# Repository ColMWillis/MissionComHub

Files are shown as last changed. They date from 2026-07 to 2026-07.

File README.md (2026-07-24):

# Mission Communications Hub Mk I

**Branding:** Mission Communications Hub / Mk I / GAWG CAP

**Current mechanical revision:** R0.12 side-by-side PD carrier and matching lid

MissionComHub is an experimental portable power-interface enclosure for a Peplink MAX BR1 Pro 5G and Starlink Mini using an Anker SOLIX C200 DC or equivalent USB-C PD source. It is designed for temporary CAP aircraft, ground-vehicle, and mission-base use.

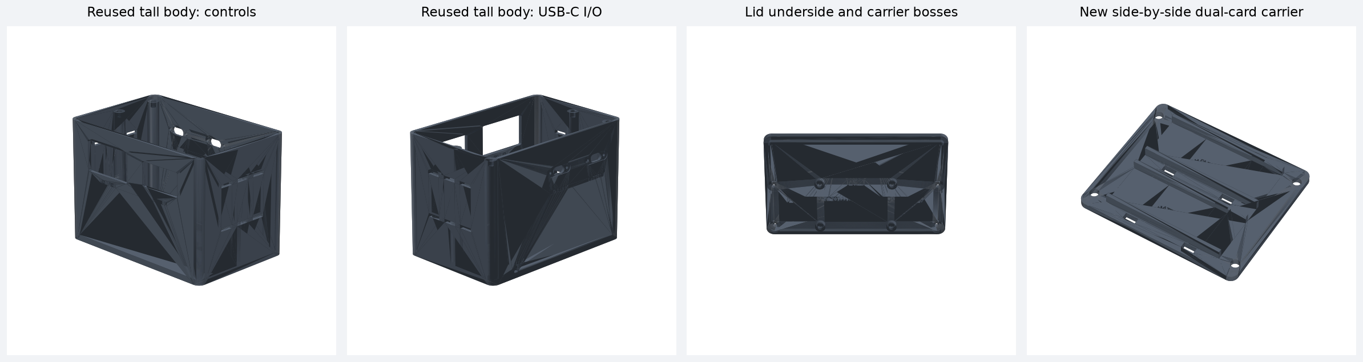
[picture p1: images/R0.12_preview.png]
Mission Communications Hub R0.12 preview


## R0.12 configuration

- 146 × 96 × 103 mm PETG-CF body
- Separate 4 mm serviceable lid with locating lip and raised branding
- Power switch opening: 38.55 × 20.77 mm
- Fit-tested voltmeter opening: 45.17 × 26.39 mm
- Two refactored USB-C panel positions for the received cable-backed fittings
- Confirmed 18.55 mm USB-C mounting centers
- 13.20 × 6.85 mm printed pass-throughs for the measured 12.70 × 6.35 mm bodies
- 25.80 × 8.02 mm rounded flange pockets for the measured 25.40 × 7.62 mm flanges
- Fit-tested 4.10 × 2.40 mm bonded-cable exit for the Peplink lead
- Enlarged 4.55 × 2.70 mm strain-relief channel and two-screw clamp
- Internal Blue Sea Systems 5045 mounting bosses at 65.1 mm centers
- Internal unfused-busbar bosses at the confirmed 120.65 mm (4.75 inch) centers
- A clear central cable channel with four tie-down points
- Correctly oriented exterior `BATTERY`, `STARLINK`, and `PEPLINK` I/O labels
- Exterior `VOLTAGE` and `POWER` control labels
- Blue Sea 5045 fused-block riser coupon
- Full-envelope unfused-busbar riser coupon with fixed 120.65 mm centers
- Final engraved USB-C coupon at 18.55 mm centers
- Revised lid with a compact four-boss carrier pattern
- Removable 64 × 54 mm side-by-side carrier for two USB-PD cards
- Rails moved inward 1 mm per side and raised 2 mm
- Open USB ends plus 20 mm power-wire service zones at the screw terminals
- Open-ended card guides and two zip ties per card
- Documented battery-input and Starlink-output card placement under the lid
- Blue Sea 5045 moved to the I/O half
- Unfused bus bar moved to the control half
- Switch, voltmeter, and USB-C interfaces raised to a 77 mm centerline
- Explicit clearance validation for the switch’s measured 38.10 mm inward depth

R0.12 reuses the validated R0.11 tall body. It replaces the tandem carrier and lid after physical fitting showed an attached USB plug extending beyond the enclosure and the received boards falling between the original rails.

## Download and print

- Complete package: [`releases/R0.12/MissionComHub_MkI_Enclosure_R0.12.zip`](releases/R0.12/MissionComHub_MkI_Enclosure_R0.12.zip)
- 3MF files: [`CAD/3MF/R0.12`](CAD/3MF/R0.12)
- STL files: [`CAD/STL/R0.12`](CAD/STL/R0.12)
- STEP files: [`CAD/STEP/R0.12`](CAD/STEP/R0.12)
- Parametric CadQuery generator: [`CAD/CadQuery/make_mch_mk1_r12.py`](CAD/CadQuery/make_mch_mk1_r12.py)
- Dimensions, placement map, and validation: [`CAD/Releases/R0.12`](CAD/Releases/R0.12)

Reuse the R0.11 body. Print the R0.12 lid and carrier; the tandem R0.10/R0.11 carrier is obsolete.

## Suggested prototype settings

- Prusa CORE One
- PETG-CF with a hardened 0.4 mm nozzle
- 0.20 mm layer height
- 4 perimeters
- 5 top and bottom layers
- 25–35% gyroid infill

The branded lid needs slicer support beneath its center when printed branding-up. See the release README for orientation guidance.

## Validation status

Every R0.12 STL and 3MF is watertight with consistent winding. STEP files re-import as valid solids. Body/lid, carrier, card, attached USB plug, power-wire service zone, switch, and both power-block checks report zero interference.

## Repository layout

- `CAD/CadQuery/` — parametric source
- `CAD/3MF/`, `CAD/STL/`, `CAD/STEP/` — synchronized manufacturing exports
- `CAD/Releases/` — dimensions, checksums, and validation reports
- `docs/` — requirements, design specification, BOM, assembly, and tests
- `images/` — previews and future build photographs
- `releases/` — complete downloadable release archives
- `tools/` — validation and preview utilities

## Safety

This is experimental mission-support equipment, not certified avionics. It must not interfere with aircraft controls, emergency egress, required equipment, weight and balance, or approved aircraft systems. Electrical architecture, wire sizing, fuse selection, thermal performance, and flight restraint must be independently verified before operational use.

## License

Documentation and mechanical designs are released under CERN-OHL-P-2.0 unless a file states otherwise. Software uses the MIT License where applicable.

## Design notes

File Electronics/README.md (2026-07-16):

# Electronics

Reserved for Milestone 2 electrical design:

- power architecture
- wiring harness drawings
- connector pinouts
- fuse schedule
- load budget
- test records

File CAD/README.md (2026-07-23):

# CAD Files

The current parametric source of truth is [`CadQuery/make_mch_mk1_r09.py`](CadQuery/make_mch_mk1_r09.py).

R0.9 final-draft exports are organized by format:

- [`3MF/R0.9`](3MF/R0.9) — print meshes in millimeter units
- [`STL/R0.9`](STL/R0.9) — triangulated print meshes
- [`STEP/R0.9`](STEP/R0.9) — neutral editable solids for Fusion and other CAD tools
- [`Releases/R0.9`](Releases/R0.9) — README, dimensions, checksums, and validation results

All three export formats were generated from the same CadQuery source. The complete packaged release is under [`../releases/R0.9`](../releases/R0.9).

## R0.9 printable objects

1. Main enclosure body
2. Branded locating-lip lid
3. Peplink bonded-cable strain-relief clamp
4. Control fit coupon
5. Final 18.55 mm USB-C fit coupon
6. Peplink wire-exit fit coupon
7. Blue Sea 5045 fused-block riser coupon
8. Unfused-busbar riser coupon at confirmed 120.65 mm centers

## R0.8A USB-C refinement coupon

`MCH-MkI_USB-C_panel_fit_coupon_18.70-18.75_R0.8A` is a focused two-position coupon created after the 18.80 mm position was slightly loose. The left opening is 18.75 mm and the right opening is 18.70 mm. The enclosure body is not changed until this coupon identifies the preferred fit.

## R0.8B fit refinement coupons

- `MCH-MkI_USB-C_panel_fit_coupon_18.60-18.65_R0.8B`: left position 18.65 mm; right position 18.60 mm.
- `MCH-MkI_unfused_busbar_riser_coupon_120.65mm_R0.8B`: fixed 120.65 mm (4.75 inch) mounting centers, 0.25 inch farther apart than the prior coupon.

Both measurements are engraved on their coupons. The enclosure body remains at the R0.8 dimensions until physical coupon testing identifies the final values.

## R0.8C USB-C refinement coupon

`MCH-MkI_USB-C_panel_fit_coupon_18.55mm_R0.8C` is a compact single-position coupon at 18.55 mm screw centers. This fit and the 120.65 mm busbar value were subsequently confirmed and incorporated into the R0.9 final draft.

Do not alter a mesh export without updating the parametric source and regenerating every synchronized format.

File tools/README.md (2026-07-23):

# Release Tools

The R0.5 validation and preview scripts require Python plus `cadquery`, `trimesh`, `numpy`, and `matplotlib`.

From the repository root:

```text
python tools/validate_release_r05.py
python tools/render_preview_r05.py
```

The validator reads the canonical files under `CAD/3MF/R0.5`, `CAD/STL/R0.5`, and `CAD/STEP/R0.5`. It updates the validation reports and repository checksums under `CAD/Releases/R0.5`.

For the current R0.6 release, use:

```text
python tools/validate_release_r06.py
python tools/render_preview_r06.py
```

For the current R0.7 release, use:

```text
python tools/validate_release_r07.py
python tools/render_preview_r07.py
```

For the current R0.8 release, use:

```text
python tools/validate_release_r08.py
python tools/render_preview_r08.py
```

For the R0.9 final draft, use:

```text
python tools/validate_release_r09.py
python tools/render_preview_r09.py
```

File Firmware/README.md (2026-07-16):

# Firmware

Reserved for future monitoring, display, telemetry, and network-management software. No firmware is required for the Milestone 1 enclosure.

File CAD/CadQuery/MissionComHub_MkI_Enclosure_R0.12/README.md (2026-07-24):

# Mission Communications Hub Mk I Enclosure R0.12 — Side-by-Side PD Carrier

Compact refactor based on measured components.

## Overall size
- Body: 146 x 96 x 103 mm
- Wall: 3.0 mm
- Separate 4.0 mm lid with locating lip and raised branding

## Control face
- Voltmeter opening: 45.17 x 26.39 mm
- Power switch opening: 38.55 x 20.77 mm

R0.12 reuses the validated R0.11 tall body and replaces the tandem PD carrier and its lid mounting pattern.

## R0.12 collision correction
- Body height: 103.0 mm, increased by 51.0 mm (2.01 inches)
- Measured switch inward depth: 38.10 mm
- Control and USB panel center height: 77.0 mm
- Unfused bus bar: control half, Y=-24.95 mm
- Blue Sea 5045 fused block: I/O half, Y=+22.10 mm
- Tall lid posts moved to the I/O half and kept outside the fused-block footprint

## I/O face
- Two measured panel mounts: 25.4 x 7.62 mm rounded flange, 18.55 mm confirmed screw centers
- Received pass-through body: 12.70 x 6.35 mm
- Printed connector opening: 13.20 x 6.85 mm; M2.5 clearance holes: 2.8 mm
- Flush flange pocket: 25.8 x 8.0 x 0.8 mm deep
- Peplink bonded-cable exit: 4.10 x 2.40 mm rounded slot
- Reduced two-screw strain-relief for the measured 3.81 x 2.03 mm bonded 20 AWG cable
- Strain-relief cable channel: 4.55 x 2.70 mm
- Correctly oriented engraved BATTERY, STARLINK, and PEPLINK labels
- Engraved VOLTAGE and POWER control-face labels

## Blue Sea 5045 mounting
- Documented body footprint reserved: 92.5 x 43.8 mm
- Two internal mounting bosses at 65.1 mm centers
- 3.6 mm pilot holes; verify the chosen M4 fastening method before final assembly
- Full riser coupon included
- Mounted in the I/O half after the R0.11 block swap

## Unfused bus bar
- Supplied cover envelope: 137.16 x 38.10 x 22.86 mm
- Supplied lower-base length: 119.38 mm
- Confirmed mounting centers: 120.65 mm (4.75 inches)
- Body and coupon use fixed 5.5 mm mounting holes
- Body enlarged to 146 x 96 mm so the covered block and fused block can mount side-by-side
- Mounted in the control half after the R0.11 block swap

## Cable accommodation
The obsolete PCB-backed USB shelves were removed because the received USB interfaces are cable-backed panel fittings. Routing rails and tie-down tabs retain service loops away from both power blocks.

## USB-PD card carrier
- Separate removable carrier: 64.0 x 54.0 x 2.4 mm
- Installs under the lid, centered at X=0, Y=17.0 mm over the fused-block half
- Two open-ended bays for 45.72 x 17.78 mm card envelopes
- Two parallel side-by-side bays; both USB-C sockets point toward +X
- Battery-input PD card occupies the lower-Y bay; Starlink-output PD card occupies the upper-Y bay
- Guide rails move inward 1.0 mm per side and rise to 3.6 mm
- USB ends remain open for attached plugs; screw-terminal ends remain open with 20 mm validated wire-service envelopes
- Two zip ties per card; no undocumented PCB mounting holes are assumed
- Four M3 screws secure the carrier to blind heat-set-insert bosses under the lid
- The flat carrier face mounts against the lid bosses; the guide rails and cards face into the enclosure
- A conservative 8.0 mm card-assembly depth clears the bus-bar cover in the validated assembly

See `PD_CARD_PLACEMENT.md` for the top-view map, assembly order, and wiring paths.

## Print order
1. Stop using the R0.9/R0.10 body for this hardware layout.
2. Reuse the validated R0.11 body; print the R0.12 lid and R0.12 carrier.
3. Do not reuse the tandem R0.10/R0.11 carrier.
4. Install four M3 heat-set inserts in the blind underside bosses.
5. Fit the two cards to the carrier with two small zip ties per card.
6. Attach the populated carrier to the lid with four M3 screws.
7. Reuse the R0.10 strain-relief clamp if already printed; its geometry is unchanged.

## Suggested print settings
- PETG-CF
- 0.4 mm hardened nozzle
- 0.20 mm layer height
- 4 perimeters
- 5 top/bottom layers
- 25-35% gyroid infill
- Body upright; lid branding upward
- Carrier rail-side upward; no support is expected
- Body: supports only where the slicer identifies control/I-O openings as necessary
- Lid: branding upward preserves the visible text; enable snug/organic supports beneath the broad center panel, or test a long-edge orientation with a brim

## Serviceability
- The 4 mm removable lid, corrected locating lip, and raised branding are preserved, with its body-screw holes relocated to the I/O half.
- The entire PD assembly comes away with the lid after four enclosure screws are removed.
- Leave service loops in both USB panel cables and the DC wiring before lifting the lid.
- Mk II shall add a captive hinge/tether so the wire harness never acts as the lid restraint.
- All external component geometry has a fit coupon. Print coupons before the body.
- The final USB coupon and both body interfaces use the confirmed 18.55 mm screw centers.
- The Blue Sea 5045 footprint is based on the manufacturer's documented 92.5 x 43.8 mm envelope and 65.1 mm mounting centers.

## Regenerating the files
Python 3.11 or newer is recommended. Install `cadquery` and `trimesh`, then run:

```text
python make_mch_mk1_r12.py
```

The generator writes synchronized STEP, STL, and millimeter-unit 3MF files into a `MissionComHub_MkI_Enclosure_R0.12` folder beside the script.

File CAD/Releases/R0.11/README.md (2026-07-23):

# Mission Communications Hub Mk I Enclosure R0.11 — Tall Swapped-Block Body

Compact refactor based on measured components.

## Overall size
- Body: 146 x 96 x 103 mm
- Wall: 3.0 mm
- Separate 4.0 mm lid with locating lip and raised branding

## Control face
- Voltmeter opening: 45.17 x 26.39 mm
- Power switch opening: 38.55 x 20.77 mm

R0.11 replaces the R0.10 body after the physical 38.10 mm switch depth conflicted with the fused block. The body is approximately 2 inches taller, the fused and unfused blocks exchange sides, and all panel controls are raised into a dedicated upper zone.

## R0.11 collision correction
- Body height: 103.0 mm, increased by 51.0 mm (2.01 inches)
- Measured switch inward depth: 38.10 mm
- Control and USB panel center height: 77.0 mm
- Unfused bus bar: control half, Y=-24.95 mm
- Blue Sea 5045 fused block: I/O half, Y=+22.10 mm
- Tall lid posts moved to the I/O half and kept outside the fused-block footprint

## I/O face
- Two measured panel mounts: 25.4 x 7.62 mm rounded flange, 18.55 mm confirmed screw centers
- Received pass-through body: 12.70 x 6.35 mm
- Printed connector opening: 13.20 x 6.85 mm; M2.5 clearance holes: 2.8 mm
- Flush flange pocket: 25.8 x 8.0 x 0.8 mm deep
- Peplink bonded-cable exit: 4.10 x 2.40 mm rounded slot
- Reduced two-screw strain-relief for the measured 3.81 x 2.03 mm bonded 20 AWG cable
- Strain-relief cable channel: 4.55 x 2.70 mm
- Correctly oriented engraved BATTERY, STARLINK, and PEPLINK labels
- Engraved VOLTAGE and POWER control-face labels

## Blue Sea 5045 mounting
- Documented body footprint reserved: 92.5 x 43.8 mm
- Two internal mounting bosses at 65.1 mm centers
- 3.6 mm pilot holes; verify the chosen M4 fastening method before final assembly
- Full riser coupon included
- Mounted in the I/O half after the R0.11 block swap

## Unfused bus bar
- Supplied cover envelope: 137.16 x 38.10 x 22.86 mm
- Supplied lower-base length: 119.38 mm
- Confirmed mounting centers: 120.65 mm (4.75 inches)
- Body and coupon use fixed 5.5 mm mounting holes
- Body enlarged to 146 x 96 mm so the covered block and fused block can mount side-by-side
- Mounted in the control half after the R0.11 block swap

## Cable accommodation
The obsolete PCB-backed USB shelves were removed because the received USB interfaces are cable-backed panel fittings. Routing rails and tie-down tabs retain service loops away from both power blocks.

## USB-PD card carrier
- Separate removable carrier: 114.0 x 30.0 x 2.4 mm
- Installs under the lid, centered at X=0, Y=25.0 mm over the fused-block half
- Two open-ended bays for 45.72 x 17.78 mm card envelopes
- Left bay: battery-input PD sink/trigger card
- Right bay: Starlink-output PD source card
- Two zip ties per card; no undocumented PCB mounting holes are assumed
- Four M3 screws secure the carrier to blind heat-set-insert bosses under the lid
- The flat carrier face mounts against the lid bosses; the guide rails and cards face into the enclosure
- A conservative 8.0 mm card-assembly depth clears the bus-bar cover in the validated assembly

See `PD_CARD_PLACEMENT.md` for the top-view map, assembly order, and wiring paths.

## Print order
1. Stop using the R0.9/R0.10 body for this hardware layout.
2. Print the complete R0.11 body and R0.11 lid.
3. Reuse an R0.10 carrier if already printed; its geometry is unchanged.
4. Install four M3 heat-set inserts in the blind underside bosses.
5. Fit the two cards to the carrier with two small zip ties per card.
6. Attach the populated carrier to the lid with four M3 screws.
7. Reuse the R0.10 strain-relief clamp if already printed; its geometry is unchanged.

## Suggested print settings
- PETG-CF
- 0.4 mm hardened nozzle
- 0.20 mm layer height
- 4 perimeters
- 5 top/bottom layers
- 25-35% gyroid infill
- Body upright; lid branding upward
- Carrier rail-side upward; no support is expected
- Body: supports only where the slicer identifies control/I-O openings as necessary
- Lid: branding upward preserves the visible text; enable snug/organic supports beneath the broad center panel, or test a long-edge orientation with a brim

## Serviceability
- The 4 mm removable lid, corrected locating lip, and raised branding are preserved, with its body-screw holes relocated to the I/O half.
- The entire PD assembly comes away with the lid after four enclosure screws are removed.
- Leave service loops in both USB panel cables and the DC wiring before lifting the lid.
- All external component geometry has a fit coupon. Print coupons before the body.
- The final USB coupon and both body interfaces use the confirmed 18.55 mm screw centers.
- The Blue Sea 5045 footprint is based on the manufacturer's documented 92.5 x 43.8 mm envelope and 65.1 mm mounting centers.

## Regenerating the files
Python 3.11 or newer is recommended. Install `cadquery` and `trimesh`, then run:

```text
python make_mch_mk1_r11.py
```

The generator writes synchronized STEP, STL, and millimeter-unit 3MF files into a `MissionComHub_MkI_Enclosure_R0.11` folder beside the script.

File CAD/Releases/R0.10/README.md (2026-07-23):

# Mission Communications Hub Mk I Enclosure R0.10 — USB-PD Carrier

Compact refactor based on measured components.

## Overall size
- Body: 146 x 96 x 52 mm
- Wall: 3.0 mm
- Separate 4.0 mm lid with locating lip and raised branding

## Control face
- Voltmeter opening: 45.17 x 26.39 mm
- Power switch opening: 38.55 x 20.77 mm

R0.10 preserves the physically confirmed R0.9 enclosure body and adds a removable dual USB-PD card carrier to a revised lid. The already-printing R0.9 body remains fully compatible.

## I/O face
- Two measured panel mounts: 25.4 x 7.62 mm rounded flange, 18.55 mm confirmed screw centers
- Received pass-through body: 12.70 x 6.35 mm
- Printed connector opening: 13.20 x 6.85 mm; M2.5 clearance holes: 2.8 mm
- Flush flange pocket: 25.8 x 8.0 x 0.8 mm deep
- Peplink bonded-cable exit: 4.10 x 2.40 mm rounded slot
- Reduced two-screw strain-relief for the measured 3.81 x 2.03 mm bonded 20 AWG cable
- Strain-relief cable channel: 4.55 x 2.70 mm
- Correctly oriented engraved BATTERY, STARLINK, and PEPLINK labels
- Engraved VOLTAGE and POWER control-face labels

## Blue Sea 5045 mounting
- Documented body footprint reserved: 92.5 x 43.8 mm
- Two internal mounting bosses at 65.1 mm centers
- 3.6 mm pilot holes; verify the chosen M4 fastening method before final assembly
- Full riser coupon included

## Unfused bus bar
- Supplied cover envelope: 137.16 x 38.10 x 22.86 mm
- Supplied lower-base length: 119.38 mm
- Confirmed mounting centers: 120.65 mm (4.75 inches)
- Body and coupon use fixed 5.5 mm mounting holes
- Body enlarged to 146 x 96 mm so the covered block and fused block can mount side-by-side

## Cable accommodation
The obsolete PCB-backed USB shelves were removed because the received USB interfaces are cable-backed panel fittings. Routing rails and tie-down tabs retain service loops away from both power blocks.

## USB-PD card carrier
- Separate removable carrier: 114.0 x 30.0 x 2.4 mm
- Installs under the lid, centered at X=0, Y=25.0 mm over the unfused bus bar
- Two open-ended bays for 45.72 x 17.78 mm card envelopes
- Left bay: battery-input PD sink/trigger card
- Right bay: Starlink-output PD source card
- Two zip ties per card; no undocumented PCB mounting holes are assumed
- Four M3 screws secure the carrier to blind heat-set-insert bosses under the lid
- The flat carrier face mounts against the lid bosses; the guide rails and cards face into the enclosure
- A conservative 8.0 mm card-assembly depth clears the bus-bar cover in the validated assembly

See `PD_CARD_PLACEMENT.md` for the top-view map, assembly order, and wiring paths.

## Print order
1. Keep or finish the R0.9 body; no body reprint is required.
2. Print the R0.10 lid and dual USB-PD card carrier.
3. Install four M3 heat-set inserts in the blind underside bosses.
4. Fit the two cards to the carrier with two small zip ties per card.
5. Attach the populated carrier to the lid with four M3 screws.
6. Print the strain-relief clamp only if an R0.9 clamp is not already available.

## Suggested print settings
- PETG-CF
- 0.4 mm hardened nozzle
- 0.20 mm layer height
- 4 perimeters
- 5 top/bottom layers
- 25-35% gyroid infill
- Body upright; lid branding upward
- Carrier rail-side upward; no support is expected
- Body: supports only where the slicer identifies control/I-O openings as necessary
- Lid: branding upward preserves the visible text; enable snug/organic supports beneath the broad center panel, or test a long-edge orientation with a brim

## Serviceability
- The R0.6 4 mm removable lid, corrected locating lip, M3 corner-boss pattern, and raised branding are preserved.
- The entire PD assembly comes away with the lid after four enclosure screws are removed.
- Leave service loops in both USB panel cables and the DC wiring before lifting the lid.
- All external component geometry has a fit coupon. Print coupons before the body.
- The final USB coupon and both body interfaces use the confirmed 18.55 mm screw centers.
- The Blue Sea 5045 footprint is based on the manufacturer's documented 92.5 x 43.8 mm envelope and 65.1 mm mounting centers.

## Regenerating the files
Python 3.11 or newer is recommended. Install `cadquery` and `trimesh`, then run:

```text
python make_mch_mk1_r10.py
```

The generator writes synchronized STEP, STL, and millimeter-unit 3MF files into a `MissionComHub_MkI_Enclosure_R0.10` folder beside the script.

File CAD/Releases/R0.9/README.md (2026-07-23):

# Mission Communications Hub Mk I Enclosure R0.9 Final Draft

Compact refactor based on measured components.

## Overall size
- Body: 146 x 96 x 52 mm
- Wall: 3.0 mm
- Separate 4.0 mm lid with locating lip and raised branding

## Control face
- Voltmeter opening: 45.17 x 26.39 mm
- Power switch opening: 38.55 x 20.77 mm

R0.9 incorporates all physically confirmed interface dimensions into the complete enclosure body. It is the final draft before full assembly testing.

## I/O face
- Two measured panel mounts: 25.4 x 7.62 mm rounded flange, 18.55 mm confirmed screw centers
- Received pass-through body: 12.70 x 6.35 mm
- Printed connector opening: 13.20 x 6.85 mm; M2.5 clearance holes: 2.8 mm
- Flush flange pocket: 25.8 x 8.0 x 0.8 mm deep
- Peplink bonded-cable exit: 4.10 x 2.40 mm rounded slot
- Reduced two-screw strain-relief for the measured 3.81 x 2.03 mm bonded 20 AWG cable
- Strain-relief cable channel: 4.55 x 2.70 mm
- Correctly oriented engraved BATTERY, STARLINK, and PEPLINK labels
- Engraved VOLTAGE and POWER control-face labels

## Blue Sea 5045 mounting
- Documented body footprint reserved: 92.5 x 43.8 mm
- Two internal mounting bosses at 65.1 mm centers
- 3.6 mm pilot holes; verify the chosen M4 fastening method before final assembly
- Full riser coupon included

## Unfused bus bar
- Supplied cover envelope: 137.16 x 38.10 x 22.86 mm
- Supplied lower-base length: 119.38 mm
- Confirmed mounting centers: 120.65 mm (4.75 inches)
- Body and coupon use fixed 5.5 mm mounting holes
- Body enlarged to 146 x 96 mm so the covered block and fused block can mount side-by-side

## Cable accommodation
The obsolete PCB-backed USB shelves were removed because the received USB interfaces are cable-backed panel fittings. Routing rails and tie-down tabs retain service loops away from both power blocks.

## Print order
1. Print the final USB-C, control, wire-exit, fused-block, and unfused-block coupons if reconfirmation is desired.
2. Print the body, lid and strain-relief clamp.
3. Record any full-assembly findings before promoting the design to R1.0.

## Suggested print settings
- PETG-CF
- 0.4 mm hardened nozzle
- 0.20 mm layer height
- 4 perimeters
- 5 top/bottom layers
- 25-35% gyroid infill
- Body upright; lid branding upward
- Body: supports only where the slicer identifies control/I-O openings as necessary
- Lid: branding upward preserves the visible text; enable snug/organic supports beneath the broad center panel, or test a long-edge orientation with a brim

## Serviceability
- The R0.6 4 mm removable lid, corrected locating lip, M3 corner-boss pattern, and raised branding are preserved.
- All external component geometry has a fit coupon. Print coupons before the body.
- The final USB coupon and both body interfaces use the confirmed 18.55 mm screw centers.
- The Blue Sea 5045 footprint is based on the manufacturer's documented 92.5 x 43.8 mm envelope and 65.1 mm mounting centers.

## Regenerating the files
Python 3.11 or newer is recommended. Install `cadquery` and `trimesh`, then run:

```text
python make_mch_mk1_r09.py
```

The generator writes synchronized STEP, STL, and millimeter-unit 3MF files into a `MissionComHub_MkI_Enclosure_R0.9` folder beside the script.

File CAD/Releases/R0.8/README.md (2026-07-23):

# Mission Communications Hub Mk I Enclosure R0.8

Compact refactor based on measured components.

## Overall size
- Body: 146 x 96 x 52 mm
- Wall: 3.0 mm
- Separate 4.0 mm lid with locating lip and raised branding

## Control face
- Voltmeter opening: 45.17 x 26.39 mm
- Power switch opening: 38.55 x 20.77 mm

R0.8 preserves all physically verified control and Peplink cutouts while rebuilding the USB-C interface around the received component and adding the received unfused bus bar to the body.

## I/O face
- Two measured panel mounts: 25.4 x 7.62 mm rounded flange, 19.05 mm nominal screw centers
- Received pass-through body: 12.70 x 6.35 mm
- Printed connector opening: 13.20 x 6.85 mm; M2.5 clearance holes: 2.8 mm
- Flush flange pocket: 25.8 x 8.0 x 0.8 mm deep
- Peplink bonded-cable exit: 4.10 x 2.40 mm rounded slot
- Reduced two-screw strain-relief for the measured 3.81 x 2.03 mm bonded 20 AWG cable
- Strain-relief cable channel: 4.55 x 2.70 mm
- Correctly oriented engraved BATTERY, STARLINK, and PEPLINK labels
- Engraved VOLTAGE and POWER control-face labels

## Blue Sea 5045 mounting
- Documented body footprint reserved: 92.5 x 43.8 mm
- Two internal mounting bosses at 65.1 mm centers
- 3.6 mm pilot holes; verify the chosen M4 fastening method before final assembly
- Full riser coupon included

## Unfused bus bar
- Supplied cover envelope: 137.16 x 38.10 x 22.86 mm
- Supplied lower-base length: 119.38 mm
- Physical mounting centers: 114.30 mm (4.5 inches)
- Body and coupon use fixed 5.5 mm mounting holes
- Body enlarged to 146 x 96 mm so the covered block and fused block can mount side-by-side

## Cable accommodation
The obsolete PCB-backed USB shelves were removed because the received USB interfaces are cable-backed panel fittings. Routing rails and tie-down tabs retain service loops away from both power blocks.

## Print order
1. Print the control, USB-C, wire-exit, fused-block, and unfused-block coupons.
2. Test the switch, voltmeter, both USB-C panel fittings, and bonded Peplink cable.
3. Adjust the parameters at the top of `make_mch_mk1_r08.py` if necessary.
4. Print the body, lid and strain-relief clamp.

## Suggested print settings
- PETG-CF
- 0.4 mm hardened nozzle
- 0.20 mm layer height
- 4 perimeters
- 5 top/bottom layers
- 25-35% gyroid infill
- Body upright; lid branding upward
- Body: supports only where the slicer identifies control/I-O openings as necessary
- Lid: branding upward preserves the visible text; enable snug/organic supports beneath the broad center panel, or test a long-edge orientation with a brim

## Serviceability
- The R0.6 4 mm removable lid, corrected locating lip, M3 corner-boss pattern, and raised branding are preserved.
- All external component geometry has a fit coupon. Print coupons before the body.
- The USB coupon provides 18.80, 19.05, and 19.30 mm screw-center variants; the body uses 19.05 mm.
- The Blue Sea 5045 footprint is based on the manufacturer's documented 92.5 x 43.8 mm envelope and 65.1 mm mounting centers.

## Regenerating the files
Python 3.11 or newer is recommended. Install `cadquery` and `trimesh`, then run:

```text
python make_mch_mk1_r08.py
```

The generator writes a synchronized STEP, STL, and millimeter-unit 3MF for each part into a `MissionComHub_MkI_Enclosure_R0.8` folder beside the script.

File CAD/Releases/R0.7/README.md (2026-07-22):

# Mission Communications Hub Mk I Enclosure R0.7

Compact refactor based on measured components.

## Overall size
- Body: 140 x 90 x 52 mm
- Wall: 3.0 mm
- Separate 4.0 mm lid with locating lip and raised branding

## Control face
- Voltmeter opening: 45.17 x 26.39 mm
- Power switch opening: 38.55 x 20.77 mm

R0.7 preserves all physically verified R0.6 cutouts and corrects the exterior I/O label orientation. It adds VOLTAGE and POWER control-face labels plus separate fused and unfused power-block riser coupons.

## I/O face
- Two AAOTOKK panel mounts: 33.0 x 25.0 mm flange, 25.0 mm screw centers
- Connector opening: 11.0 x 6.0 mm; M2.5 clearance holes: 2.8 mm
- Flush flange pocket: 33.4 x 25.4 x 0.8 mm deep
- Peplink bonded-cable exit: 4.10 x 2.40 mm rounded slot
- Reduced two-screw strain-relief for the measured 3.81 x 2.03 mm bonded 20 AWG cable
- Strain-relief cable channel: 4.55 x 2.70 mm
- Correctly oriented engraved BATTERY, STARLINK, and PEPLINK labels
- Engraved VOLTAGE and POWER control-face labels

## Blue Sea 5045 mounting
- Documented body footprint reserved: 92.5 x 43.8 mm
- Two internal mounting bosses at 65.1 mm centers
- 3.6 mm pilot holes; verify the chosen M4 fastening method before final assembly
- Full riser coupon included

## Unfused bus bar (provisional)
- Supplied cover envelope: 137.16 x 38.10 x 22.86 mm
- Supplied lower-base length: 119.38 mm
- Provisional coupon uses 8.0 x 5.8 mm elongated riser slots at nominal 106.5 mm centers
- The cover is 3.16 mm longer than the current 134.0 mm internal enclosure length, so the body does not yet include this block
- Do not freeze body bosses until the physical block verifies its footprint and mounting centers

## PD board accommodation
Two universal cradles are sized around a 17.78 x 43.18 mm board, with an additional 2.54 mm solder-joint allowance. They are rotated along X to preserve the fuse-block footprint. Routing rails and four zip-tie tabs keep service loops away from fuse terminals.

## Print order
1. Print the control, USB-C, wire-exit, fused-block, and unfused-block coupons.
2. Test the switch, voltmeter, both AAOTOKK receptacles, and bonded Peplink cable.
3. Adjust the parameters at the top of `make_mch_mk1_r07.py` if necessary.
4. Print the body, lid and strain-relief clamp.

## Suggested print settings
- PETG-CF
- 0.4 mm hardened nozzle
- 0.20 mm layer height
- 4 perimeters
- 5 top/bottom layers
- 25-35% gyroid infill
- Body upright; lid branding upward
- Body: supports only where the slicer identifies control/I-O openings as necessary
- Lid: branding upward preserves the visible text; enable snug/organic supports beneath the broad center panel, or test a long-edge orientation with a brim

## Serviceability
- The R0.6 4 mm removable lid, corrected locating lip, M3 corner-boss pattern, and raised branding are preserved.
- All external component geometry has a fit coupon. Print coupons before the body.
- The AAOTOKK flange dimensions came from the supplied dimension image; verify screw spacing and recess fit on the coupon.
- The Blue Sea 5045 footprint is based on the manufacturer's documented 92.5 x 43.8 mm envelope and 65.1 mm mounting centers.

## Regenerating the files
Python 3.11 or newer is recommended. Install `cadquery` and `trimesh`, then run:

```text
python make_mch_mk1_r07.py
```

The generator writes a synchronized STEP, STL, and millimeter-unit 3MF for each part into a `MissionComHub_MkI_Enclosure_R0.7` folder beside the script.

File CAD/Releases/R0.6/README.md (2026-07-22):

# Mission Communications Hub Mk I Enclosure R0.6

Compact refactor based on measured components.

## Overall size
- Body: 140 x 90 x 52 mm
- Wall: 3.0 mm
- Separate 4.0 mm lid with locating lip and raised branding

## Control face
- Voltmeter opening: 45.17 x 26.39 mm
- Power switch opening: 38.55 x 20.77 mm

R0.6 preserves the physically verified R0.5 switch and voltmeter openings. It selects the smallest Peplink wire-coupon opening and enlarges the strain-relief cable channel by 0.50 mm overall in both dimensions.

## I/O face
- Two AAOTOKK panel mounts: 33.0 x 25.0 mm flange, 25.0 mm screw centers
- Connector opening: 11.0 x 6.0 mm; M2.5 clearance holes: 2.8 mm
- Flush flange pocket: 33.4 x 25.4 x 0.8 mm deep
- Peplink bonded-cable exit: 4.10 x 2.40 mm rounded slot
- Reduced two-screw strain-relief for the measured 3.81 x 2.03 mm bonded 20 AWG cable
- Strain-relief cable channel: 4.55 x 2.70 mm
- Engraved BATTERY, STARLINK, and PEPLINK labels

## Blue Sea 5045 mounting
- Documented body footprint reserved: 92.5 x 43.8 mm
- Two internal mounting bosses at 65.1 mm centers
- 3.6 mm pilot holes; verify the chosen M4 fastening method before final assembly

## PD board accommodation
Two universal cradles are sized around a 17.78 x 43.18 mm board, with an additional 2.54 mm solder-joint allowance. They are rotated along X to preserve the fuse-block footprint. Routing rails and four zip-tie tabs keep service loops away from fuse terminals.

## Print order
1. Print the three fit coupons.
2. Test the switch, voltmeter, both AAOTOKK receptacles, and bonded Peplink cable.
3. Adjust the parameters at the top of `make_mch_mk1_r06.py` if necessary.
4. Print the body, lid and strain-relief clamp.

## Suggested print settings
- PETG-CF
- 0.4 mm hardened nozzle
- 0.20 mm layer height
- 4 perimeters
- 5 top/bottom layers
- 25-35% gyroid infill
- Body upright; lid branding upward
- Body: supports only where the slicer identifies control/I-O openings as necessary
- Lid: branding upward preserves the visible text; enable snug/organic supports beneath the broad center panel, or test a long-edge orientation with a brim

## Serviceability
- The R0.5 4 mm removable lid, corrected locating lip, M3 corner-boss pattern, and raised branding are preserved.
- All external component geometry has a fit coupon. Print coupons before the body.
- The AAOTOKK flange dimensions came from the supplied dimension image; verify screw spacing and recess fit on the coupon.
- The Blue Sea 5045 footprint is based on the manufacturer's documented 92.5 x 43.8 mm envelope and 65.1 mm mounting centers.

## Regenerating the files
Python 3.11 or newer is recommended. Install `cadquery` and `trimesh`, then run:

```text
python make_mch_mk1_r06.py
```

The generator writes a synchronized STEP, STL, and millimeter-unit 3MF for each part into a `MissionComHub_MkI_Enclosure_R0.6` folder beside the script.

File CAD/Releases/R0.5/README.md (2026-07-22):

# Mission Communications Hub Mk I Enclosure R0.5

Compact refactor based on measured components.

## Overall size
- Body: 140 x 90 x 52 mm
- Wall: 3.0 mm
- Separate 4.0 mm lid with locating lip and raised branding

## Control face
- Voltmeter opening: 45.17 x 26.39 mm
- Power switch opening: 38.55 x 20.77 mm

R0.5 widens the R0.4 voltmeter opening by 1.00 mm total (0.50 mm on the left and right) while preserving the verified 26.39 mm height.

## I/O face
- Two AAOTOKK panel mounts: 33.0 x 25.0 mm flange, 25.0 mm screw centers
- Connector opening: 11.0 x 6.0 mm; M2.5 clearance holes: 2.8 mm
- Flush flange pocket: 33.4 x 25.4 x 0.8 mm deep
- Peplink bonded-cable exit: 4.35 x 2.65 mm rounded slot
- Reduced two-screw strain-relief for the measured 3.81 x 2.03 mm bonded 20 AWG cable
- Engraved BATTERY, STARLINK, and PEPLINK labels

## Blue Sea 5045 mounting
- Documented body footprint reserved: 92.5 x 43.8 mm
- Two internal mounting bosses at 65.1 mm centers
- 3.6 mm pilot holes; verify the chosen M4 fastening method before final assembly

## PD board accommodation
Two universal cradles are sized around a 17.78 x 43.18 mm board, with an additional 2.54 mm solder-joint allowance. They are rotated along X to preserve the fuse-block footprint. Routing rails and four zip-tie tabs keep service loops away from fuse terminals.

## Print order
1. Print the three fit coupons.
2. Test the switch, voltmeter, both AAOTOKK receptacles, and bonded Peplink cable.
3. Adjust the parameters at the top of `make_mch_mk1_r05.py` if necessary.
4. Print the body, lid and strain-relief clamp.

## Suggested print settings
- PETG-CF
- 0.4 mm hardened nozzle
- 0.20 mm layer height
- 4 perimeters
- 5 top/bottom layers
- 25-35% gyroid infill
- Body upright; lid branding upward
- Body: supports only where the slicer identifies control/I-O openings as necessary
- Lid: branding upward preserves the visible text; enable snug/organic supports beneath the broad center panel, or test a long-edge orientation with a brim

## Serviceability
- The R0.4 4 mm removable lid, corrected locating lip, M3 corner-boss pattern, and raised branding are preserved.
- All external component geometry has a fit coupon. Print coupons before the body.
- The AAOTOKK flange dimensions came from the supplied dimension image; verify screw spacing and recess fit on the coupon.
- The Blue Sea 5045 footprint is based on the manufacturer's documented 92.5 x 43.8 mm envelope and 65.1 mm mounting centers.

## Regenerating the files
Python 3.11 or newer is recommended. Install `cadquery` and `trimesh`, then run:

```text
python make_mch_mk1_r05.py
```

The generator writes a synchronized STEP, STL, and millimeter-unit 3MF for each part into a `MissionComHub_MkI_Enclosure_R0.5` folder beside the script.

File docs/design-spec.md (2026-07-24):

# Mechanical Design Specification — Mk I R0.12 Side-by-Side PD Carrier

## Identification and scope

- Product: Mission Communications Hub
- Marking: `Mission Communications Hub / Mk I / GAWG CAP`
- Revision: R0.12 side-by-side PD carrier and matching lid
- Function: portable power-interface enclosure for Peplink MAX BR1 Pro 5G and Starlink Mini
- External source: Anker SOLIX C200 DC or equivalent USB-C PD source

The enclosure does not contain the Peplink, Starlink Mini, iPad, battery, or certified avionics. The Starlink Mini remains external so it can be positioned at a window. An iPad may be powered directly from an available battery port and is not assigned a dedicated R0.5 enclosure connector.

## Envelope and construction

| Feature | R0.11 value |
|---|---:|
| Body envelope | 146 × 96 × 103 mm |
| Wall thickness | 3.0 mm |
| Bottom thickness | 3.2 mm |
| External corner radius | 6.0 mm |
| Lid plate | 4.0 mm |
| Lid locating-lip depth | 3.5 mm |
| Lid clearance | 0.35 mm per side |
| Lid fasteners | Four M3 positions |

The body and lid are separate, serviceable printed parts. R0.3 corrected the inherited locating-lip interference and added clearance pockets around the body’s corner bosses. Automated assembly checking reports 0 mm³ body/lid interference.

R0.11 adds 51 mm (approximately 2 inches) of body height after physical fitting established that the switch extends 38.10 mm into the enclosure. The panel centerline moves from 26 mm to 77 mm above the base.

## Control face

- Power switch nominal body: 38.10 × 20.32 mm
- Switch cutout: 38.55 × 20.77 mm
- Measured switch inward depth: 38.10 mm
- Voltmeter nominal supplied size: 45.72 × 27.94 mm
- Fit-tested R0.5/R0.6 voltmeter cutout: 45.17 × 26.39 mm
- Outside control labels: `VOLTAGE` and `POWER`

The voltmeter opening evolved through physical coupon testing:

- R0.3: 46.17 × 28.39 mm — retained but rattled
- R0.4: 44.17 × 26.39 mm — correct vertically, tight horizontally
- R0.5: 45.17 × 26.39 mm — adds 0.50 mm on each side

## I/O face

Two received cable-backed USB-C panel-mount positions are labeled `BATTERY` and `STARLINK`. R0.8 retains the corrected outside-reading label orientation.

| Feature | Dimension |
|---|---:|
| Measured pass-through body | 12.70 × 6.35 mm |
| Printed pass-through | 13.20 × 6.85 mm |
| Measured rounded flange | 25.40 × 7.62 mm |
| Flush recess | 25.80 × 8.02 × 0.8 mm deep |
| Confirmed screw centers | 18.55 mm |
| Screw clearance | 2.8 mm diameter |

The body and final USB coupon use the physically confirmed 18.55 mm centers.

The `PEPLINK` exit is designed around a measured bonded red/black 20 AWG pair:

- Cable: 3.81 × 2.03 mm
- Fit-tested body exit: 4.10 × 2.40 mm
- R0.6 strain-relief channel: 4.55 × 2.70 mm
- Clamp: 18 × 10 × 3.6 mm with two M3 positions

The smallest R0.5 wire-coupon opening fit correctly. The first strain-relief channel was too tight, so R0.6 adds 0.50 mm overall in both channel dimensions without changing the cover footprint or screw spacing.

## Internal geometry

- Blue Sea Systems 5045 reserved envelope: 92.5 × 43.8 mm
- Mounting-boss centers: 65.1 mm
- Boss pilot holes: 3.6 mm; final M4 fastening method must be physically verified
- Unfused busbar cover envelope: 137.16 × 38.10 × 22.86 mm
- Unfused busbar mounting centers: physically confirmed 120.65 mm
- Unfused busbar mounting-hole diameter in R0.8: 5.5 mm
- Four zip-tie tabs occupy the clear channel between the power blocks

R0.11 places the Blue Sea 5045 at Y=+22.1 mm in the I/O half and the unfused busbar at Y=−24.95 mm in the control half. Tall lid posts move to Y=0 and +39 mm, with X=±66 mm keeping them outside the fused-block footprint.

## USB-PD carrier

- A 64 × 54 × 2.4 mm removable carrier mounts under the R0.12 lid.
- Four blind 4.6 mm M3 insert pilots are arranged on 58 × 42 mm centers.
- Two side-by-side, open-ended bays accept 45.72 × 17.78 mm card envelopes.
- Board centers are X = 0 mm at Y = +4.5 mm and +29.5 mm.
- Both USB-C sockets point toward +X; both screw-terminal ends point toward −X.
- The guide rails move inward 1 mm per side and rise from 1.6 to 3.6 mm.
- Each terminal end retains a 20 mm wire-service and bend zone.
- Two zip ties retain each card without assuming a PCB mounting-hole pattern.
- The R0.11 tall body is reusable; the R0.10/R0.11 tandem carrier is not.

## Material and printing

- Printer target: Prusa CORE One
- Material: PETG-CF
- Hardened 0.4 mm nozzle
- 0.20 mm layer height
- 4 perimeters
- 5 top and bottom layers
- 25–35% gyroid infill

Print fit coupons first. The body is printed upright. The raised branding complicates the lid orientation: printing branding-up requires support beneath the broad center panel; a long-edge orientation with a brim may also be tested.

## Branding

The lid carries centered raised text:

```text
Mission Communications Hub
Mk I
GAWG CAP
```

No CAP seal or insignia is included.

## Validation

R0.11 passed automated checks for:

- watertight STL and 3MF meshes
- consistent mesh winding and positive volume
- millimeter-unit 3MF package structure
- matching STL and 3MF extents
- successful STEP solid re-import
- exact 146 × 96 × 103 mm body envelope
- zero body/lid intersection when assembled
- zero conservative-envelope intersection between either power block and the body or the other block
- zero installed-carrier intersection with the body or either power block
- zero conservative PD-card-envelope intersection with the body or either power block
- zero intersection between the 38.10 mm-deep switch envelope and either power block
- 24.405 mm vertical clearance between the lowest control opening and the taller conservative power-block envelope

Automated validation does not replace physical fit, load, thermal, vibration, restraint, or electrical testing.

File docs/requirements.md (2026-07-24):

# Mk I R0.12 Side-by-Side PD Carrier Requirements

Requirement identifiers remain stable. Retired conceptual requirements are preserved and not reassigned.

## Mechanical

- MCH-M-001: The R0.11 body shall measure 146 × 96 × 103 mm.
- MCH-M-002: The enclosure shall use a separate body and removable locating-lip lid.
- MCH-M-003: Lid service points shall use M3 machine-screw positions suitable for inserts.
- MCH-M-004: **Retired** — removable electronics sled.
- MCH-M-005: **Retired** — replaceable front and rear panels.
- MCH-M-006: **Deferred** — AMPS mounting pattern.
- MCH-M-007: **Deferred** — integrated 25 mm strap paths.
- MCH-M-008: The enclosure shall have rounded external corners and no sharp cable-contact edges.
- MCH-M-009: Normal lid and strain-relief service shall not require destructive removal of printed parts.
- MCH-M-010: Blue Sea 5045 bosses shall use 65.1 mm mounting centers.
- MCH-M-011: The Peplink body exit shall use the physically verified 4.10 × 2.40 mm opening.
- MCH-M-012: Internal routing features shall retain wiring away from fuse terminals and lid screws.
- MCH-M-013: The strain-relief cable channel shall measure 4.55 × 2.70 mm while preserving the R0.5 clamp footprint and screw spacing.
- MCH-M-014: The Blue Sea 5045 and unfused busbar shall each have a printable mounting-fit coupon.
- MCH-M-015: The unfused busbar shall mount at the physically confirmed 120.65 mm centers.
- MCH-M-016: The covered unfused busbar and Blue Sea 5045 envelopes shall not intersect the body or each other above their mounting risers.
- MCH-M-017: A removable lid-mounted carrier shall retain two side-by-side 45.72 × 17.78 mm USB-PD card envelopes.
- MCH-M-018: The carrier shall use four M3 fasteners into blind lid bosses on 58 × 42 mm centers.
- MCH-M-019: Each PD card shall use two independent zip-tie retention points.
- MCH-M-020: Conservative 8 mm-deep PD-card envelopes shall not intersect the body, fused block, or unfused busbar.
- MCH-M-021: The Blue Sea 5045 shall occupy the I/O half and the unfused busbar shall occupy the control half.
- MCH-M-022: The switch, voltmeter, and USB-C interface centerline shall be 77 mm above the base.
- MCH-M-023: A 38.10 mm-deep switch envelope shall not intersect either conservative power-block envelope.
- MCH-M-024: Both USB-C sockets shall point toward +X and retain attached-plug clearance inside the enclosure.
- MCH-M-025: Both screw-terminal ends shall remain open with at least 20 mm of wire-service space.
- MCH-M-026: Carrier rails shall be 3.6 mm high and moved inward 1 mm per side relative to R0.11.

## Deferred Mk II requirement

- MCH-MKII-M-001: The lid shall remain mechanically captive to the body when its service screws are removed. A hinge, tether, or equivalent restraint shall support the lid so the wiring harness never acts as the lid restraint.

## Printing and release

- MCH-P-001: Every primary printed part shall fit the Prusa CORE One build volume.
- MCH-P-002: Primary parts shall be printable in PETG-CF with a hardened 0.4 mm nozzle.
- MCH-P-003: No inaccessible support material shall be required.
- MCH-P-004: Each release shall include STEP, STL, and 3MF files generated from one parametric source.
- MCH-P-005: Every 3MF shall declare millimeter units and match its corresponding STL dimensions.
- MCH-P-006: Control, USB-C, wire-exit, fused-block, and unfused-block fit coupons shall be supplied.

## Interfaces

- MCH-I-001: **Retired** — four Anderson Powerpole output positions.
- MCH-I-002: **Retired** — PEPLINK/STARLINK/AUX 1/AUX 2 Powerpole labels.
- MCH-I-003: The enclosure shall provide one received-style USB-C panel position labeled `BATTERY`.
- MCH-I-004: The enclosure shall provide one master-switch opening.
- MCH-I-005: The enclosure shall provide one fit-tested voltage-display opening.
- MCH-I-006: **Retired** — expansion blanking plates.
- MCH-I-007: The enclosure shall provide one received-style USB-C panel position labeled `STARLINK`.
- MCH-I-008: The enclosure shall provide one bonded-cable exit labeled `PEPLINK`.
- MCH-I-009: The I/O labels shall read correctly when viewed from outside the enclosure.
- MCH-I-010: The control face shall be labeled `VOLTAGE` and `POWER`.
- MCH-I-011: Each USB-C interface shall provide a 13.20 × 6.85 mm rounded pass-through and a 25.80 × 8.02 mm rounded flange recess.
- MCH-I-012: Both USB-C interfaces shall use the physically confirmed 18.55 mm screw centers.

## Branding

- MCH-B-001: The lid shall display `Mission Communications Hub`.
- MCH-B-002: The lid shall display `Mk I`.
- MCH-B-003: The lid shall display `GAWG CAP`.
- MCH-B-004: Branding shall remain legible in a single-color print.

## Safety and serviceability

- MCH-S-001: No energized conductor shall be finger-accessible with the lid installed.
- MCH-S-002: External cable loads shall be transferred to panel hardware or strain relief rather than solder joints.
- MCH-S-003: The Peplink bonded cable shall use the printed two-screw strain-relief clamp.
- MCH-S-004: Circuit protection, wire sizing, and component ratings shall be verified before energized operation.
- MCH-S-005: Internal wiring shall be retained away from lid fasteners and fuse terminals.
- MCH-S-006: This prototype shall not be represented as certified avionics.

## Documentation

- MCH-D-001: Each release shall include a BOM.
- MCH-D-002: Each release shall include assembly guidance.
- MCH-D-003: Each release shall include a dimensions manifest.
- MCH-D-004: Each release shall include automated validation results and checksums.
- MCH-D-005: Physical coupon-fit feedback shall be recorded in the changelog.
- MCH-D-006: The release shall include a PD-card placement and wiring map.

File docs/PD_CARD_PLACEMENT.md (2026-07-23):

# USB-PD Card Placement — R0.10

This map is viewed from above with the lid removed. The I/O face (BATTERY,
STARLINK, and PEPLINK) is at the top.

```text
                         I/O FACE (+Y)
   BATTERY USB-C           STARLINK USB-C          PEPLINK
          |                       |                    |
+----------------------------------------------------------------+
|                                                                |
|   +----------------------+  +----------------------+            |
|   | BATTERY PD CARD      |  | STARLINK PD CARD     |            |
|   | X = -27, Y = +25     |  | X = +27, Y = +25    |            |
|   | 45.72 x 17.78 mm     |  | 45.72 x 17.78 mm    |            |
|   +----------------------+  +----------------------+            |
|   <--------- removable carrier, under the lid ----------->      |
|                                                                |
|   ================== UNFUSED BUS BAR ======================      |
|                                                                |
|       cable/tie-down channel between the two power blocks       |
|                                                                |
|              BLUE SEA 5045 FUSED BLOCK                          |
|                                                                |
|        VOLTAGE                              POWER                |
+----------------------------------------------------------------+
                       CONTROL FACE (-Y)
```

## Mechanical placement

- Carrier center: **X 0, Y +25.0 mm**.
- Battery card center: **X -27.0, Y +25.0 mm**.
- Starlink card center: **X +27.0, Y +25.0 mm**.
- Card long axes run left-to-right, parallel to the 146 mm enclosure dimension.
- The carrier's flat face seats against the four lid bosses.
- The printed guide rails, labels, zip ties, and cards face downward into the box.
- Install two small zip ties per board using the paired slots.
- The carrier comes off with four M3 screws; the body does not need to be reprinted.

## Lid preparation

1. Print the R0.10 lid branding-side upward.
2. Heat-set four M3 inserts into the blind bosses on the underside.
3. Stop each insert flush with the bottom of its boss; do not force it toward the branded surface.
4. Populate the carrier before fastening it to the lid.
5. Use M3 screws short enough to engage the insert without bottoming out; verify length against the actual inserts.

## Card identity

- **Left / BATTERY PD:** the USB-C PD sink/trigger card that negotiates power from the Anker battery.
- **Right / STARLINK PD:** the USB-C PD source card that provides the required profile to the Starlink Mini.
- Do not interchange the cards unless their electrical functions and voltage profiles are confirmed.

## Wiring path

```text
Anker C200
   -> BATTERY panel USB-C cable
   -> BATTERY PD sink/trigger card
   -> master POWER switch
   -> Blue Sea 5045 positive feed and unfused negative bus

Blue Sea fused branch
   -> Peplink bonded cable

Blue Sea fused branch + negative return
   -> STARLINK PD source card
   -> STARLINK panel USB-C cable

Switched positive + negative bus
   -> VOLTAGE meter
```

## Service loops and clearance

- Leave a gentle service loop in both USB panel cables so the lid can be raised before disconnecting them.
- Tie the loops to the body's central tabs; do not pull them tight across fuse or bus-bar terminals.
- Keep all conductors below the lid perimeter and away from the four enclosure screw bosses.
- Automated clearance validation uses a conservative **8.0 mm** total card/component depth.
- Before energizing, close the lid without screws and confirm that no component, solder joint, or wire is being compressed.

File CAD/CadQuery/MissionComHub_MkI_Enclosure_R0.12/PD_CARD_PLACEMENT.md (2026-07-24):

# USB-PD Card Placement — R0.12

This map is viewed from above with the lid removed. The I/O face (BATTERY,
STARLINK, and PEPLINK) is at the top.

```text
                         I/O FACE (+Y)
   BATTERY USB-C           STARLINK USB-C          PEPLINK
          |                       |                    |
+----------------------------------------------------------------+
|                                                                |
|               USB-C ends and attached plugs -> +X              |
|          +-------------------------------------------+           |
|          | STARLINK PD  X=0, Y=+29.5               |           |
|          |-------------------------------------------|           |
|          | BATTERY PD   X=0, Y=+4.5                |           |
|          +-------------------------------------------+           |
|     open screw-terminal ends <- 20 mm wire service zone         |
|                                                                |
|              BLUE SEA 5045 FUSED BLOCK                          |
|                                                                |
|       cable/tie-down channel between the two power blocks       |
|                                                                |
|   ================== UNFUSED BUS BAR ======================      |
|                                                                |
|        VOLTAGE                              POWER                |
+----------------------------------------------------------------+
                       CONTROL FACE (-Y)
```

## Mechanical placement

- Carrier center: **X 0, Y +17.0 mm**.
- Battery card center: **X 0, Y 4.5 mm**.
- Starlink card center: **X 0, Y +29.5 mm**.
- Card long axes run left-to-right, parallel to the 146 mm enclosure dimension.
- Both USB-C sockets point toward +X; both screw-terminal ends point toward -X.
- Keep at least **20 mm** clear beyond each screw-terminal end for conductors and bend relief.
- The carrier's flat face seats against the four lid bosses.
- The printed guide rails, labels, zip ties, and cards face downward into the box.
- Install two small zip ties per board using the paired slots.
- R0.12 reuses the taller R0.11 body and its swapped power-block mounting layout.
- The tandem R0.10/R0.11 carrier cannot be reused.

## Lid preparation

1. Print the R0.12 lid branding-side upward.
2. Heat-set four M3 inserts into the blind bosses on the underside.
3. Stop each insert flush with the bottom of its boss; do not force it toward the branded surface.
4. Populate the carrier before fastening it to the lid.
5. Use M3 screws short enough to engage the insert without bottoming out; verify length against the actual inserts.

## Card identity

- **Lower-Y / BATTERY PD:** the USB-C PD sink/trigger card that negotiates power from the Anker battery.
- **Upper-Y / STARLINK PD:** the USB-C PD source card that provides the required profile to the Starlink Mini.
- Do not interchange the cards unless their electrical functions and voltage profiles are confirmed.

## Wiring path

```text
Anker C200
   -> BATTERY panel USB-C cable
   -> BATTERY PD sink/trigger card
   -> master POWER switch
   -> Blue Sea 5045 positive feed and unfused negative bus

Blue Sea fused branch
   -> Peplink bonded cable

Blue Sea fused branch + negative return
   -> STARLINK PD source card
   -> STARLINK panel USB-C cable

Switched positive + negative bus
   -> VOLTAGE meter
```

## Service loops and clearance

- Leave a gentle service loop in both USB panel cables so the lid can be raised before disconnecting them.
- Tie the loops to the body's central tabs; do not pull them tight across fuse or bus-bar terminals.
- Keep all conductors below the lid perimeter and away from the four enclosure screw bosses.
- Automated clearance validation uses a conservative **8.0 mm** total card/component depth.
- Before energizing, close the lid without screws and confirm that no component, solder joint, or wire is being compressed.

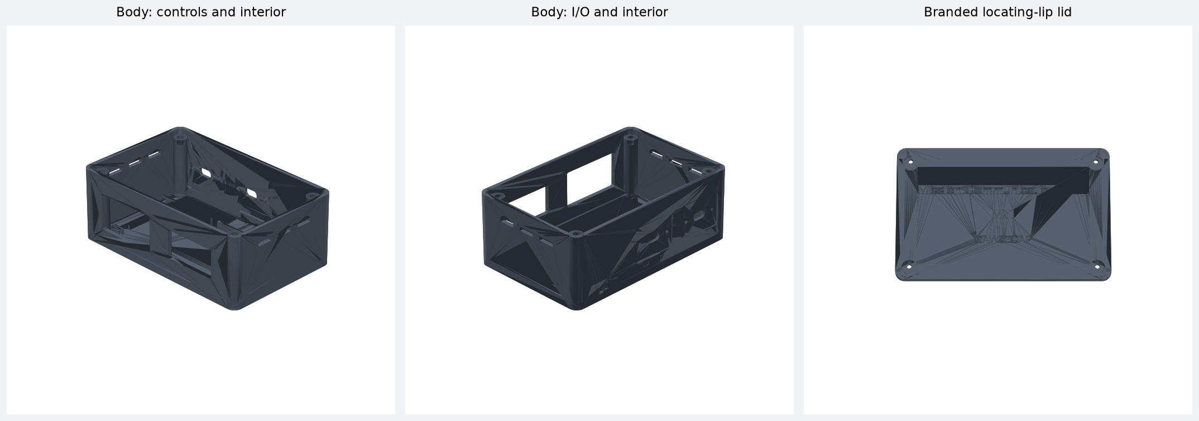
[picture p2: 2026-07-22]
images/R0.6_preview.png

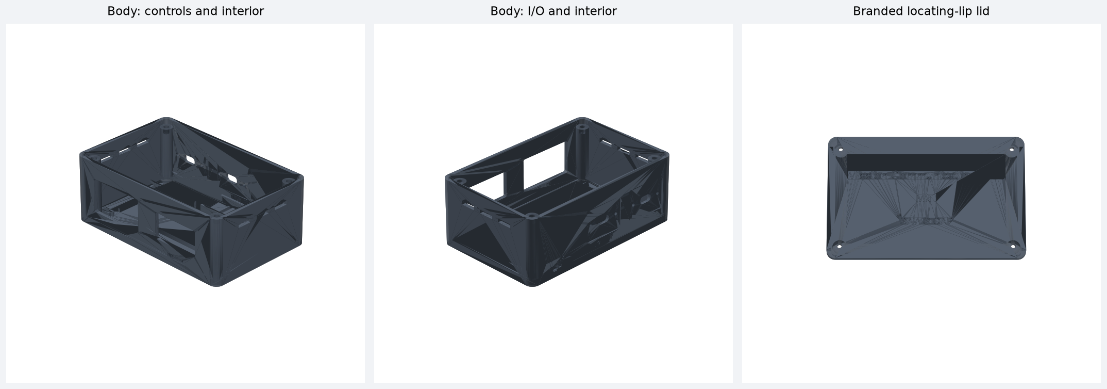
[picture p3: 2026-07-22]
images/R0.7_preview.png

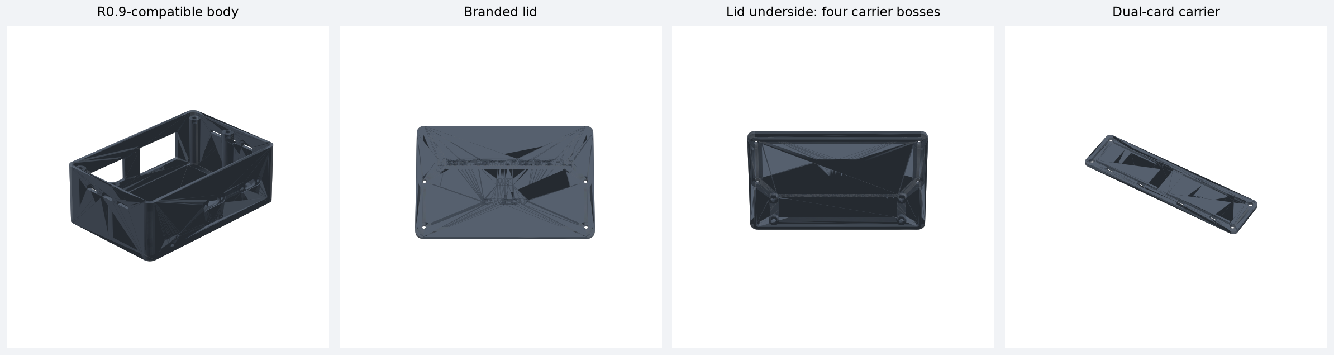
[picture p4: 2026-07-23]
images/R0.10_preview.png

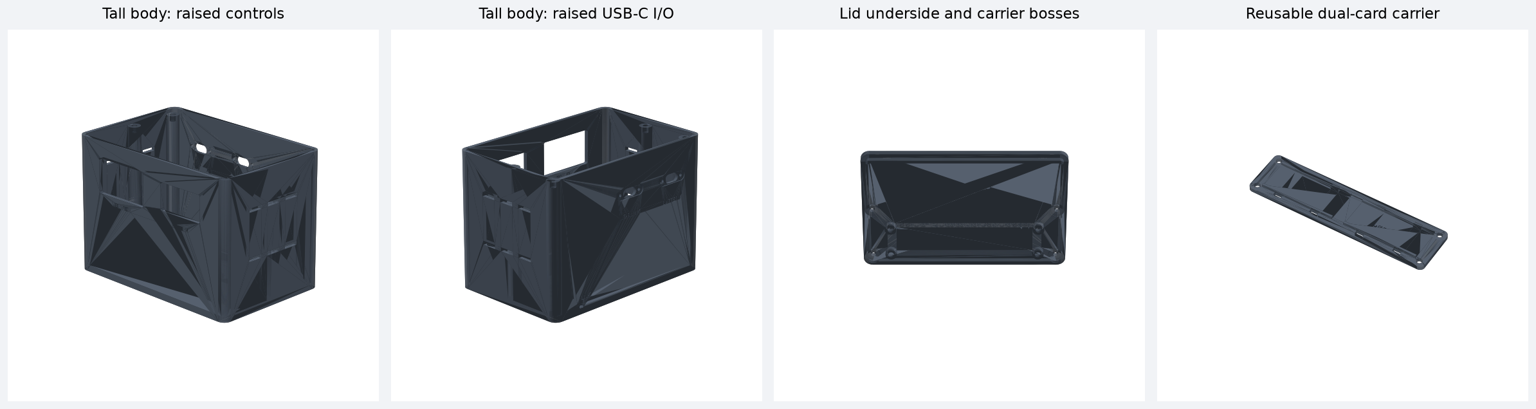
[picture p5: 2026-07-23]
images/R0.11_preview.png

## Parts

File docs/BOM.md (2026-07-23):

# Bill of Materials — Mk I R0.11 Tall Swapped-Block Body

This BOM records the components around which the R0.11 geometry was designed. Electrical ratings and final wiring remain subject to verification.

## Printed parts

| Ref | Qty | Part | Release file |
|---|---:|---|---|
| ENC-001 | 1 | 103 mm tall swapped-block body | `MCH-MkI_body_R0.11` |
| ENC-002 | 1 | Matching branded lid with relocated body screws | `MCH-MkI_lid_R0.11` |
| ENC-003 | 1 | Peplink cable clamp; R0.10 part is reusable | `MCH-MkI_peplink_strain_relief_R0.11` |
| ENC-004 | 1 | Dual USB-PD card carrier; R0.10 part is reusable | `MCH-MkI_dual_USB-PD_card_carrier_R0.11` |
| TST-001 | 1 | Control fit coupon | `MCH-MkI_control_fit_coupon_R0.11` |
| TST-002 | 1 | Final USB-C fit coupon | `MCH-MkI_USB-C_final_fit_coupon_R0.11` |
| TST-003 | 1 | Wire-exit fit coupon | `MCH-MkI_wire_exit_fit_coupon_R0.11` |
| TST-004 | 1 | Blue Sea 5045 fused-block riser coupon | `MCH-MkI_BlueSea5045_fused_block_riser_coupon_R0.11` |
| TST-005 | 1 | Unfused-busbar riser coupon | `MCH-MkI_unfused_busbar_riser_coupon_R0.11` |

Recommended enclosure material is PETG-CF printed on a Prusa CORE One with a hardened nozzle.

## Installed and interfacing hardware

| Ref | Qty | Item | Geometry/status |
|---|---:|---|---|
| CON-001 | 2 | Received USB-C cable-backed panel fitting | 12.70 × 6.35 mm pass-through; 25.40 × 7.62 mm rounded flange; confirmed 18.55 mm screw centers |
| SW-001 | 1 | Master power switch | 38.55 × 20.77 mm cutout; measured 38.10 mm inward depth |
| DSP-001 | 1 | DC voltmeter | R0.5 fit-tested 45.17 × 26.39 mm cutout |
| FUS-001 | 1 | Blue Sea Systems 5045 compact four-circuit fuse block | I/O half; 92.5 × 43.8 mm reserved; 65.1 mm boss centers |
| BUS-001 | 1 | Received unfused 12-position busbar | Control half; 137.16 × 38.10 × 22.86 mm cover; confirmed 120.65 mm mounting centers |
| PWR-001 | 1 | Battery-input USB-C PD sink/trigger card | Left carrier bay; 17.78 × 43.18 mm board plus 2.54 mm solder allowance |
| PWR-002 | 1 | Starlink-output USB-C PD source card | Right carrier bay; 17.78 × 43.18 mm board plus 2.54 mm solder allowance |
| CAB-001 | 1 | Mobile Must Have fused Peplink DC cable | Bonded 20 AWG pair; 4.10 × 2.40 mm body exit and 4.55 × 2.70 mm clamp channel |
| HW-001 | 8 | M3 heat-set inserts | Four enclosure-lid inserts plus four blind carrier-boss inserts; verify pilot fit in PETG-CF |
| HW-002 | 8 | M3 screws | Four lid and four carrier screws; select lengths after insert installation |
| HW-003 | 2 | M3 clamp screws/inserts | Match strain-relief geometry |
| HW-004 | 2–4 | USB-C panel screws/nuts | M2.5 class; 2.8 mm printed clearance holes |
| HW-005 | 2 | Blue Sea mounting fasteners | M4-class; verify 3.6 mm printed pilot strategy |
| RET-001 | 4 + as req. | Miniature cable ties | Two per PD card plus body cable-management ties |
| INS-001 | As req. | Adhesive-lined heat shrink | Harness protection |
| WIR-001 | As req. | Appropriately rated stranded wire | Size from verified electrical loads and protection |

## External equipment

- Anker SOLIX C200 DC power source
- Peplink MAX BR1 Pro 5G
- Starlink Mini, positioned outside the enclosure
- iPad, normally powered directly from an available battery USB-C port

## Hold points

Before energized assembly:

1. Use the physically verified R0.5/R0.6 control dimensions.
2. Use the physically confirmed 18.55 mm USB-C screw centers.
3. Confirm the bonded cable in the 4.10 × 2.40 mm exit and enlarged 4.55 × 2.70 mm clamp channel.
4. Select and document the M3 and M4 insert/fastener method.
5. Verify the exact PD module electrical profiles, ratings, polarity, and thermal behavior.
6. Establish final fuse and wire sizes from measured loads and manufacturer requirements.
7. Test both block coupons and verify that the selected 5.5 mm busbar mounting holes suit the supplied fasteners.

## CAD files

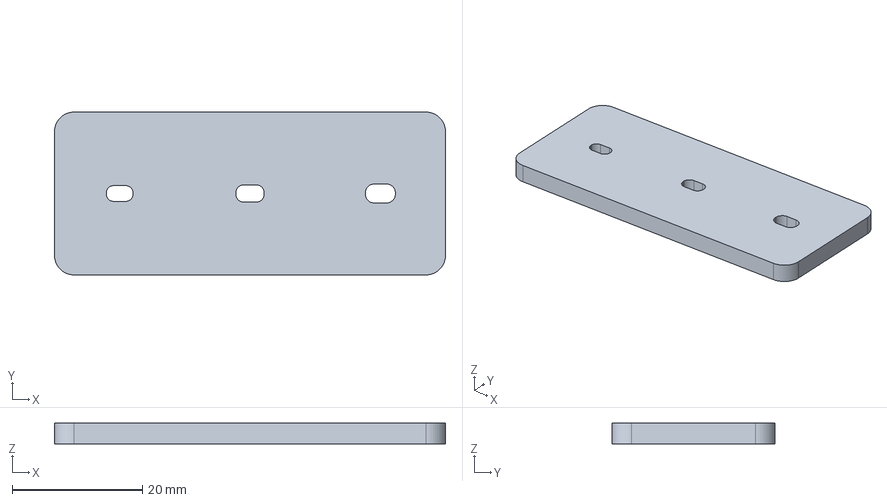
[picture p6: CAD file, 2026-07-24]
CAD/CadQuery/MissionComHub_MkI_Enclosure_R0.12/MCH-MkI_wire_exit_fit_coupon_R0.12.step
60.0 x 25.0 x 3.20 mm

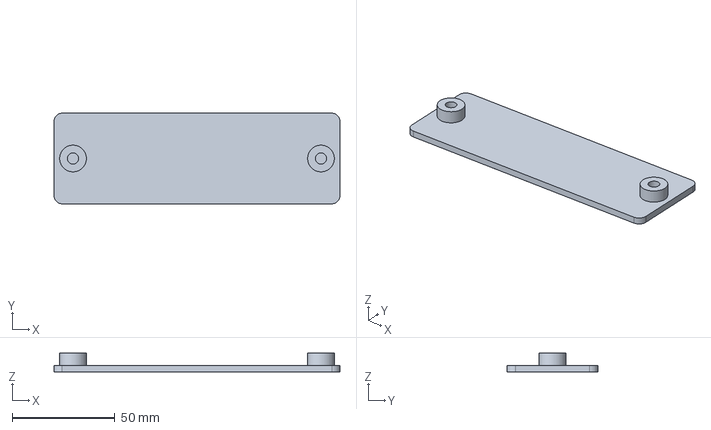
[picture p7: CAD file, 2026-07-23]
CAD/Releases/R0.8/fit-refinement-r08b/MCH-MkI_unfused_busbar_riser_coupon_120.65mm_R0.8B.step
139.2 x 44.1 x 9.20 mm

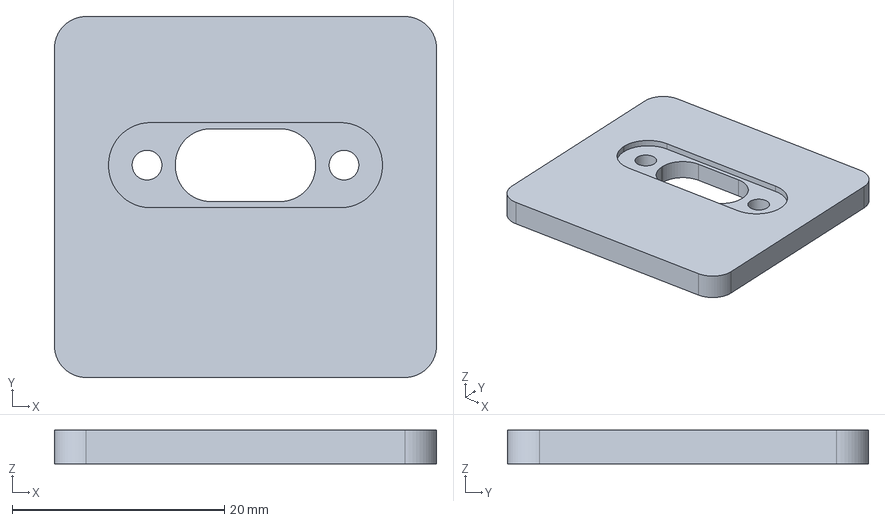
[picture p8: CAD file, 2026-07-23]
CAD/Releases/R0.8/usb-refinement-r08c/MCH-MkI_USB-C_panel_fit_coupon_18.55mm_R0.8C.step
36.0 x 34.0 x 3.20 mm

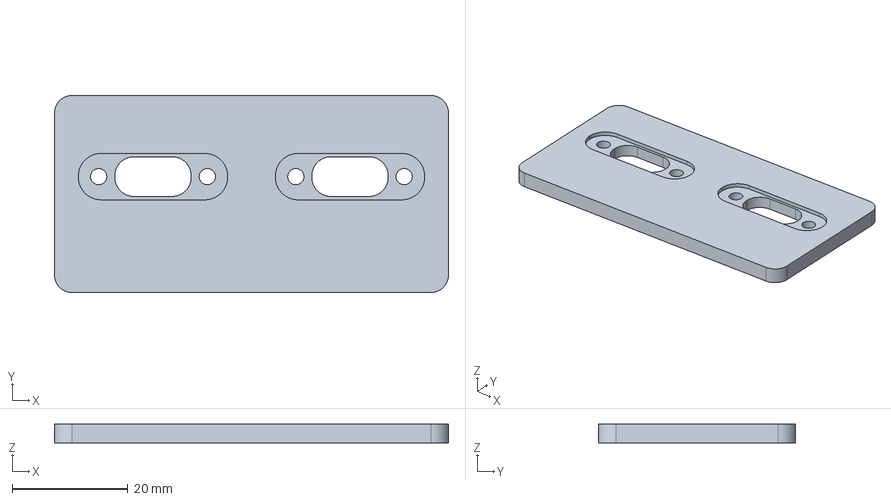
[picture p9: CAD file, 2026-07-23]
CAD/Releases/R0.8/usb-refinement/MCH-MkI_USB-C_panel_fit_coupon_18.70-18.75_R0.8A.step
68.0 x 34.0 x 3.20 mm

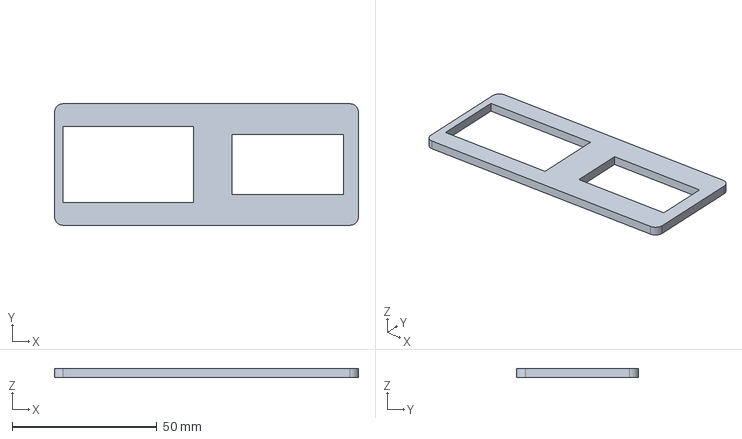
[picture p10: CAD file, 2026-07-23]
CAD/STEP/R0.10/MCH-MkI_control_fit_coupon_R0.10.step
105.0 x 42.0 x 3.20 mm

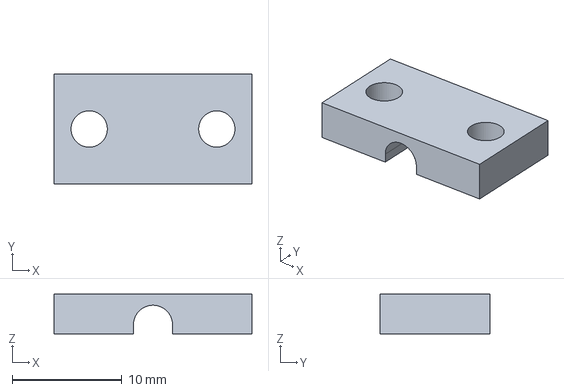
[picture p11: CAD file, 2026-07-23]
CAD/STEP/R0.11/MCH-MkI_peplink_strain_relief_R0.11.step
18.0 x 10.0 x 3.60 mm

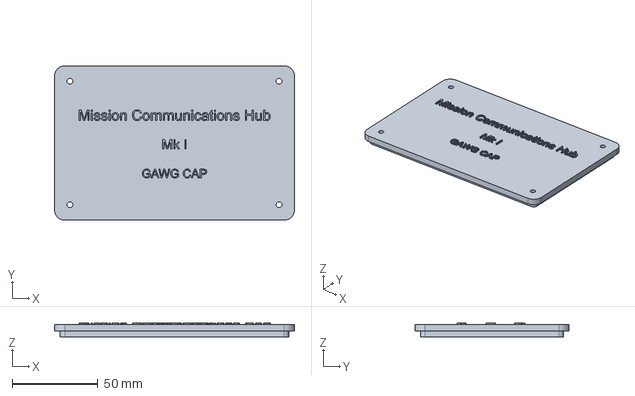
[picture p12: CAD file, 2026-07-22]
CAD/STEP/R0.5/MCH-MkI_lid_R0.5.step
140.0 x 90.0 x 8.30 mm

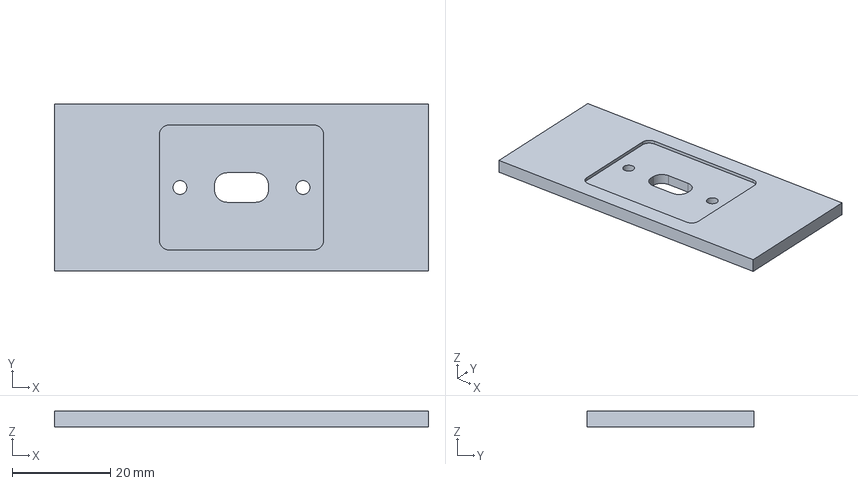
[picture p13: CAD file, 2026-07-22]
CAD/STEP/R0.6/MCH-MkI_AAOTOKK_USB-C_fit_coupon_R0.6.step
76.0 x 34.0 x 3.20 mm

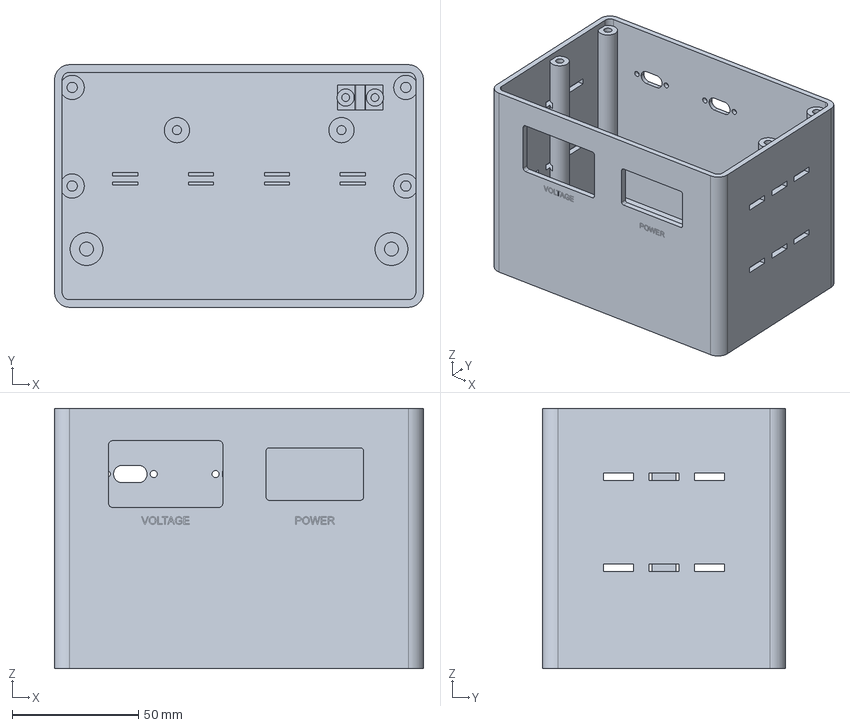
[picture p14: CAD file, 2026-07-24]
CAD/CadQuery/MissionComHub_MkI_Enclosure_R0.12/MCH-MkI_body_R0.12.step
146.0 x 96.0 x 103.0 mm

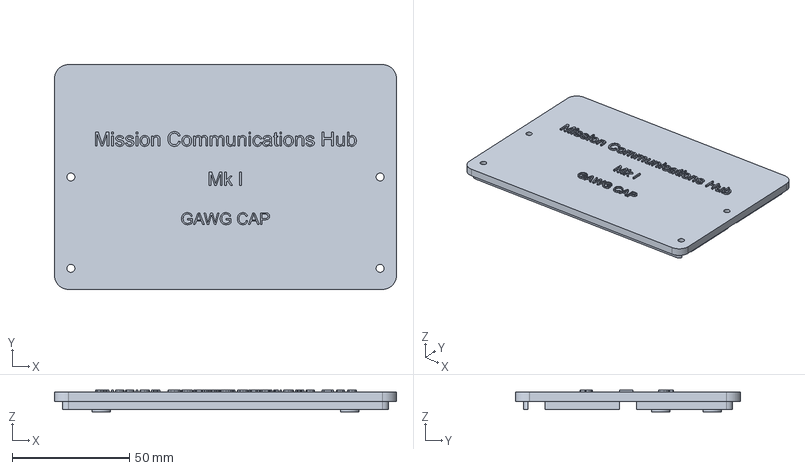
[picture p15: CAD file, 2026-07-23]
CAD/STEP/R0.10/MCH-MkI_lid_R0.10.step
146.0 x 96.0 x 9.30 mm

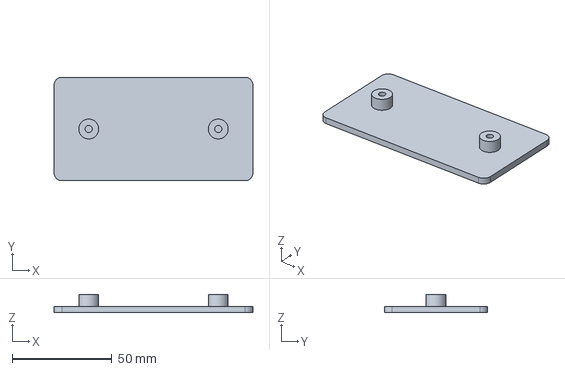
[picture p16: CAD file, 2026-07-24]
CAD/STEP/R0.12/MCH-MkI_BlueSea5045_fused_block_riser_coupon_R0.12.step
100.0 x 52.0 x 9.20 mm

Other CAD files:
CAD/STEP/R0.12/MCH-MkI_peplink_strain_relief_R0.12.step
CAD/STEP/R0.7/MCH-MkI_AAOTOKK_USB-C_fit_coupon_R0.7.step
CAD/STEP/R0.9/MCH-MkI_wire_exit_fit_coupon_R0.9.step
CAD/Releases/R0.8/fit-refinement-r08b/MCH-MkI_USB-C_panel_fit_coupon_18.60-18.65_R0.8B.step
CAD/STEP/R0.11/MCH-MkI_control_fit_coupon_R0.11.step
CAD/STEP/R0.5/MCH-MkI_peplink_strain_relief_R0.5.step
CAD/3MF/R0.10/MCH-MkI_BlueSea5045_fused_block_riser_coupon_R0.10.3mf
CAD/3MF/R0.10/MCH-MkI_USB-C_final_fit_coupon_R0.10.3mf
CAD/3MF/R0.10/MCH-MkI_body_R0.10.3mf
CAD/3MF/R0.10/MCH-MkI_control_fit_coupon_R0.10.3mf
CAD/3MF/R0.10/MCH-MkI_dual_USB-PD_card_carrier_R0.10.3mf
CAD/3MF/R0.10/MCH-MkI_lid_R0.10.3mf
CAD/3MF/R0.10/MCH-MkI_peplink_strain_relief_R0.10.3mf
CAD/3MF/R0.10/MCH-MkI_unfused_busbar_riser_coupon_R0.10.3mf
CAD/3MF/R0.10/MCH-MkI_wire_exit_fit_coupon_R0.10.3mf
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

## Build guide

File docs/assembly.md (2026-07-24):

# Assembly Guide — Mk I R0.12 Side-by-Side PD Carrier

## 1. Print and verify coupons

Use the intended PETG-CF profile for all coupons.

1. Print `MCH-MkI_control_fit_coupon_R0.11.3mf` if the verified control dimensions need reconfirmation on a different printer profile.
2. Confirm the switch snaps or seats without distorting the coupon.
3. Confirm the voltmeter fits the 45.17 × 26.39 mm opening without rattle or excessive force.
4. The final USB-C interface uses confirmed 18.55 mm screw centers. Reprint the final coupon only if the printer profile changes.
5. The R0.6 body uses the physically verified 4.10 × 2.40 mm Peplink opening. Confirm it again if the printer profile changes.
6. Print the Blue Sea 5045 fused-block coupon and verify both risers at 65.1 mm centers.
7. The final unfused-busbar coupon and body use confirmed 120.65 mm centers and 5.5 mm mounting holes.

Do not use the R0.9/R0.10 body for the final hardware layout. Its lower controls conflict with the 38.10 mm-deep switch.

## 2. Print the enclosure

- Print the body upright.
- Print the clamp flat.
- Print the lid branding-up with support under the broad center panel, or trial a long-edge orientation with a brim.
- Reuse the R0.11 tall body. Print the R0.12 lid and carrier with the carrier guide rails upward.
- Inspect every screw boss, cable-contact edge, panel recess, and locating lip before assembly.

## 3. Install threaded hardware

1. Prove the selected M3 heat-set insert pilot on scrap PETG-CF.
2. Install the four enclosure-lid inserts square to the boss faces.
3. Install four additional M3 inserts into the blind USB-PD carrier bosses under the R0.12 lid.
4. Stop the carrier inserts flush with the boss bottoms; do not force them toward the branded surface.
5. Install the two strain-relief inserts using the verified method.
6. Verify the chosen Blue Sea 5045 mounting method before modifying the 3.6 mm pilots.

Allow inserts to cool before installing screws.

## 4. Mechanical dry fit

1. Install the switch and voltmeter on the control face.
2. Install the two USB-C panel connectors on the I/O face.
3. Route the Peplink bonded pair through its exit.
4. Fit the printed clamp with its 4.55 × 2.70 mm channel and tighten only enough to prevent movement; do not flatten or cut the insulation.
5. Place the Blue Sea 5045 on the I/O-side 65.1 mm mounting centers.
6. Install the battery-input PD sink/trigger card in the lower-Y bay with its USB-C socket toward +X.
7. Install the Starlink-output PD source card in the upper-Y bay with its USB-C socket toward +X.
8. Preserve at least 20 mm of unobstructed service space beyond both screw-terminal ends.
9. Attach the populated carrier to the lid's four blind bosses with M3 screws that do not bottom in the inserts.
10. Route dummy cable through the body tie-downs and leave enough service loop to raise the lid.
11. Install the unfused busbar on the control-side 120.65 mm bosses and verify the cover clears the body, relocated lid posts, central cable channel, and populated carrier.

## 5. Lid fit

1. Place the lid locating lip into the body opening without screws.
2. Confirm the seam closes uniformly and all four holes align.
3. Install M3 screws finger-tight, then tighten evenly.
4. Confirm no screw bottoms out and no printed boss cracks.
5. Confirm the carrier guides and USB-PD cards face downward into the enclosure.
6. Confirm no solder joint, component, or wire is compressed when the lid is seated.
7. Verify the switch’s rear body and terminals remain clear of the unfused bus bar before wiring.

## 6. Electrical integration hold point

Before applying power, independently document and verify:

- USB-C PD input and output profiles
- polarity at every DC connection
- fuse ratings and source-side protection
- wire gauge and terminal ratings
- Starlink and Peplink peak loads
- switch and panel-interface DC ratings
- clearance from conductive hardware
- thermal behavior with the lid installed

## 7. Initial energized test

Perform the first test outside an aircraft on a nonflammable surface with current-limited power where practical.

1. Energize the empty distribution system and verify voltage and polarity.
2. Test the Peplink alone.
3. Test Starlink alone.
4. Test both simultaneously.
5. Run the intended maximum load for at least 30 minutes while monitoring cables, connectors, converters, fuse block, switch, and enclosure temperature.

Stop immediately for odor, discoloration, unstable voltage, unexpected resets, or abnormal heating.

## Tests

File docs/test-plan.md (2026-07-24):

# Mk I R0.12 Side-by-Side PD Carrier Test Plan

## Automated release validation

| Test ID | Method | Pass criterion | R0.12 |
|---|---|---|---|
| T-A-001 | Inspect every STL and 3MF mesh | Watertight, consistent winding, positive volume | Pass |
| T-A-002 | Compare matching STL and 3MF extents | Agreement within 0.02 mm | Pass |
| T-A-003 | Inspect 3MF package | Valid structure; millimeter units | Pass |
| T-A-004 | Re-import each STEP | At least one valid positive-volume solid | Pass |
| T-A-005 | Measure body mesh | 146 × 96 × 103 mm within 0.02 mm | Pass |
| T-A-006 | Intersect assembled body and lid STEP solids | No interference above 0.05 mm³ | Pass: 0 mm³ |
| T-A-007 | Read dimensions manifest | Voltmeter opening equals 45.17 × 26.39 mm | Pass |
| T-A-008 | Read dimensions manifest | Peplink exit equals 4.10 × 2.40 mm | Pass |
| T-A-009 | Read dimensions manifest | Strain-relief channel equals 4.55 × 2.70 mm | Pass |
| T-A-010 | Inspect block coupon exports | Both coupons are watertight and have matching STL/3MF extents | Pass |
| T-A-011 | Intersect conservative component envelopes | Fused block, unfused busbar, and body have zero intersection above risers | Pass |
| T-A-012 | Assemble carrier STEP below lid | Carrier has zero intersection with body and both power blocks | Pass |
| T-A-013 | Intersect two conservative 8 mm-deep card envelopes | Cards have zero intersection with body and both power blocks | Pass |
| T-A-014 | Measure vertical card-to-power-block clearance | Greater than 4.0 mm | Pass: 45.10 mm |
| T-A-015 | Intersect measured 38.10 mm-deep switch envelope with both power blocks | Zero intersection | Pass |
| T-A-016 | Measure lowest control opening above power blocks | Greater than 10 mm | Pass: 24.405 mm |
| T-A-017 | Add conservative attached USB-plug envelopes | Both plugs remain inside the body and clear both power blocks | Pass: 9.04 mm minimum inner-wall clearance |
| T-A-018 | Add 20 mm terminal-wire service envelopes | Both wire zones remain inside the body and clear both power blocks | Pass: 27.14 mm minimum inner-wall clearance |

Detailed values are in `CAD/Releases/R0.12/VALIDATION.md` and `validation_report.json`.

## Physical fit tests

| Test ID | Method | Pass criterion |
|---|---|---|
| T-F-001 | Fit switch in control coupon | Fully retained; no coupon distortion |
| T-F-002 | Fit voltmeter in R0.6 control coupon | Seats without rattle or excessive insertion force |
| T-F-003 | Fit received USB-C connector | Confirm the final 18.55 mm interface seats without force or movement |
| T-F-004 | Fit Peplink cable in the 4.10 × 2.40 mm opening | Passes without insulation damage |
| T-F-005 | Tighten cable clamp | Cable resists a gentle pull without visible crushing |
| T-F-006 | Fit Blue Sea 5045 | Both mounting points align at 65.1 mm centers |
| T-F-007 | Fit unfused busbar on final coupon | Base rests flat; both confirmed 120.65 mm mounting points align; supplied screws clear the 5.5 mm holes |
| T-F-008 | Inspect outside labels | BATTERY, STARLINK, PEPLINK, VOLTAGE, and POWER are readable from outside |
| T-F-009 | Fit both USB-PD cards in carrier | Cards seat between guides without force; solder extensions remain clear |
| T-F-010 | Secure each PD card with two zip ties | No card movement and no board/component crushing |

## Mechanical prototype tests

| Test ID | Method | Pass criterion |
|---|---|---|
| T-M-001 | Measure printed body | Within printer-calibrated tolerance of 146 × 96 × 103 mm |
| T-M-002 | Cycle lid screws 20 times | No stripped insert, crack, or loss of retention |
| T-M-003 | Open and close lid 20 times | Lip remains self-aligning without binding |
| T-M-004 | Shake non-energized assembled enclosure by hand | No loose hardware or component movement |
| T-M-005 | Inspect cable routes with lid installed | No wire contacts screw tips or sharp edges |
| T-M-006 | Remove and reinstall populated carrier 10 times | No insert movement, cracking, or loss of card retention |
| T-M-007 | Seat lid over populated carrier and power blocks | No compressed card, solder joint, component, or wire |
| T-M-008 | Fit switch with unfused busbar installed | Switch body and terminals remain clear through full insertion and wiring |
| T-B-001 | Inspect lid | All three branding lines are legible and centered |

## Electrical and thermal tests

These require a completed documented harness and are not satisfied by CAD validation.

| Test ID | Method | Pass criterion |
|---|---|---|
| T-E-001 | Continuity and polarity inspection before power | No short; every output polarity correct |
| T-E-002 | Peplink-only test | Stable boot and operation; no abnormal heat |
| T-E-003 | Starlink-only test | Stable boot and operation; no abnormal heat |
| T-E-004 | Combined maximum intended load for 30 minutes | No reset, odor, discoloration, hot cable, or unsafe temperature |
| T-E-005 | Verify fuse behavior using a safe test method | Correct branch interruption without harness damage |

## Deferred operational screening

- hot-soak dimensional stability
- vibration and connector-retention screening
- padded-transport drop screening
- sunlight and cockpit-temperature exposure
- restraint evaluation in each proposed aircraft or vehicle
- CAP and aircraft-owner operational approval

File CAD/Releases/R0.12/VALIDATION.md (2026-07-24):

# R0.12 Side-by-Side PD Carrier and Lid Validation Report

All matching STL, 3MF, and STEP exports passed automated validation.

R0.12 preserves the verified **45.17 × 26.39 mm** voltmeter cutout.

Peplink body exit: **4.10 × 2.40 mm**. Strain-relief channel: **4.55 × 2.70 mm**.

The USB-C panel geometry uses the received 12.70 × 6.35 mm pass-through and 25.40 × 7.62 mm rounded flange.

The body and final coupons use confirmed **18.55 mm USB** and **120.65 mm bus-bar** mounting centers.

The compact removable carrier holds two side-by-side **45.72 × 17.78 mm** card envelopes and attaches to four blind M3 insert bosses under the lid.

Both attached USB plug envelopes and both 20 mm screw-terminal wire-service envelopes clear the body and power blocks.

The 38.10 mm-deep switch envelope has zero intersection with either swapped power block.

| Part | Watertight | STL/3MF match | STEP solids | Extents (mm) |
|---|---:|---:|---:|---|
| MCH-MkI_BlueSea5045_fused_block_riser_coupon_R0.12 | Yes | Yes | 1 | 100 × 52 × 9.2 |
| MCH-MkI_USB-C_final_fit_coupon_R0.12 | Yes | Yes | 1 | 36 × 34 × 3.2 |
| MCH-MkI_body_R0.12 | Yes | Yes | 1 | 146 × 96 × 103 |
| MCH-MkI_control_fit_coupon_R0.12 | Yes | Yes | 1 | 105 × 42 × 3.2 |
| MCH-MkI_dual_USB-PD_card_carrier_R0.12 | Yes | Yes | 1 | 64 × 54 × 6 |
| MCH-MkI_lid_R0.12 | Yes | Yes | 1 | 146 × 96 × 9.3 |
| MCH-MkI_peplink_strain_relief_R0.12 | Yes | Yes | 1 | 18 × 10 × 3.6 |
| MCH-MkI_unfused_busbar_riser_coupon_R0.12 | Yes | Yes | 1 | 139.16 × 44.1 × 9.2 |
| MCH-MkI_wire_exit_fit_coupon_R0.12 | Yes | Yes | 1 | 60 × 25 × 3.2 |

Assembled body/lid interference volume: **0.000000 mm³**.

Conservative fused-block, unfused-busbar, and body envelopes have zero intersection above the mounting risers.

The lowest control opening retains **24.405 mm** vertical clearance above the conservative power-block envelopes.

The conservative 8 mm-deep PD-card envelopes retain **45.100 mm** vertical clearance above the taller power-block envelope.

Checks performed: watertightness, winding consistency, positive volume, 3MF package structure and millimeter units, STL/3MF extent agreement, STEP re-import, the 146 × 96 × 103 mm body envelope, body/lid interference, swapped power-block envelope clearance, 38.10 mm-deep switch clearance, installed carrier clearance, and conservative PD-card envelope clearance.

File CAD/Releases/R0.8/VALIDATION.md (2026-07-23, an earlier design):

# R0.8 Validation Report

All matching STL, 3MF, and STEP exports passed automated validation.

R0.8 preserves the verified **45.17 × 26.39 mm** voltmeter cutout.

Peplink body exit: **4.10 × 2.40 mm**. Strain-relief channel: **4.55 × 2.70 mm**.

The USB-C panel geometry uses the received 12.70 × 6.35 mm pass-through and 25.40 × 7.62 mm rounded flange.

The unfused-bus body and coupon use the physically measured 114.30 mm mounting centers.

| Part | Watertight | STL/3MF match | STEP solids | Extents (mm) |
|---|---:|---:|---:|---|
| MCH-MkI_BlueSea5045_fused_block_riser_coupon_R0.8 | Yes | Yes | 1 | 100 × 52 × 9.2 |
| MCH-MkI_USB-C_panel_fit_coupon_18.55mm_R0.8C | Yes | Yes | 1 | 36 × 34 × 3.2 |
| MCH-MkI_USB-C_panel_fit_coupon_18.60-18.65_R0.8B | Yes | Yes | 1 | 68 × 34 × 3.2 |
| MCH-MkI_USB-C_panel_fit_coupon_18.70-18.75_R0.8A | Yes | Yes | 1 | 68 × 34 × 3.2 |
| MCH-MkI_USB-C_panel_fit_coupon_R0.8 | Yes | Yes | 1 | 94 × 34 × 3.2 |
| MCH-MkI_body_R0.8 | Yes | Yes | 1 | 146 × 96 × 52 |
| MCH-MkI_control_fit_coupon_R0.8 | Yes | Yes | 1 | 105 × 42 × 3.2 |
| MCH-MkI_lid_R0.8 | Yes | Yes | 1 | 146 × 96 × 8.3 |
| MCH-MkI_peplink_strain_relief_R0.8 | Yes | Yes | 1 | 18 × 10 × 3.6 |
| MCH-MkI_unfused_busbar_riser_coupon_120.65mm_R0.8B | Yes | Yes | 1 | 139.16 × 44.1 × 9.2 |
| MCH-MkI_unfused_busbar_riser_coupon_R0.8 | Yes | Yes | 1 | 139.16 × 44.1 × 9.2 |
| MCH-MkI_wire_exit_fit_coupon_R0.8 | Yes | Yes | 1 | 60 × 25 × 3.2 |

Assembled body/lid interference volume: **0.000000 mm³**.

Conservative fused-block, unfused-busbar, and body envelopes have zero intersection above the mounting risers.

Checks performed: watertightness, winding consistency, positive volume, 3MF package structure and millimeter units, STL/3MF extent agreement, STEP re-import, the 146 × 96 × 52 mm body envelope, body/lid interference, and power-block envelope clearance.

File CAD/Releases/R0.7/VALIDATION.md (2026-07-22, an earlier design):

# R0.7 Validation Report

All matching STL, 3MF, and STEP exports passed automated validation.

R0.7 preserves the verified **45.17 × 26.39 mm** voltmeter cutout.

Peplink body exit: **4.10 × 2.40 mm**. Strain-relief channel: **4.55 × 2.70 mm**.

Blue Sea 5045 and provisional unfused-bus riser coupons are included. The unfused-bus mounting centers remain pending physical verification.

| Part | Watertight | STL/3MF match | STEP solids | Extents (mm) |
|---|---:|---:|---:|---|
| MCH-MkI_AAOTOKK_USB-C_fit_coupon_R0.7 | Yes | Yes | 1 | 76 × 34 × 3.2 |
| MCH-MkI_BlueSea5045_fused_block_riser_coupon_R0.7 | Yes | Yes | 1 | 100 × 52 × 9.2 |
| MCH-MkI_body_R0.7 | Yes | Yes | 1 | 140 × 90 × 52 |
| MCH-MkI_control_fit_coupon_R0.7 | Yes | Yes | 1 | 105 × 42 × 3.2 |
| MCH-MkI_lid_R0.7 | Yes | Yes | 1 | 140 × 90 × 8.3 |
| MCH-MkI_peplink_strain_relief_R0.7 | Yes | Yes | 1 | 18 × 10 × 3.6 |
| MCH-MkI_unfused_busbar_riser_coupon_R0.7 | Yes | Yes | 1 | 139.16 × 44.1 × 9.2 |
| MCH-MkI_wire_exit_fit_coupon_R0.7 | Yes | Yes | 1 | 60 × 25 × 3.2 |

Assembled body/lid interference volume: **0.000000 mm³**.

Checks performed: watertightness, winding consistency, positive volume, 3MF package structure and millimeter units, STL/3MF extent agreement, STEP re-import, the 140 × 90 × 52 mm body envelope, and body/lid interference.

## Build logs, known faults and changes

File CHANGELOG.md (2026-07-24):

# Changelog

## [Unreleased]

- Full mechanical assembly, wiring, thermal, load, and restraint testing of the R0.11 tall-body configuration.

## [R0.12] — 2026-07-24

- Replaced the tandem PD-card carrier with a 64 × 54 mm side-by-side carrier.
- Oriented both USB-C sockets toward +X so attached cables remain within the enclosure.
- Moved guide rails inward 1 mm per side and raised them from 1.6 to 3.6 mm.
- Kept both screw-terminal ends open and validated 20 mm power-wire service zones.
- Refactored the lid to the compact 58 × 42 mm carrier mounting pattern.
- Reused the validated R0.11 tall body.
- Added a deferred Mk II requirement for a captive/hinged lid restraint independent of the wiring.
- Validated zero interference for the body, lid, carrier, cards, attached USB plugs, wire-service envelopes, switch, fused block, and bus bar.

## [R0.11] — 2026-07-23

### Switch-clearance correction

- Recorded the physical switch’s 38.10 mm inward projection and the resulting R0.10 fused-block collision.
- Increased body height from 52 mm to 103 mm, adding approximately 2 inches.
- Moved the Blue Sea 5045 fused block to the I/O half.
- Moved the covered unfused bus bar to the control half.
- Raised the switch, voltmeter, and both USB-C interfaces to a 77 mm centerline.
- Moved the tall lid posts to the I/O half, outside the fused-block footprint.
- Added a second tier of side ventilation.
- Preserved the validated control cutouts, USB interfaces, Peplink exit, strain relief, and dual-card carrier.
- Validated zero intersection between the 38.10 mm-deep switch envelope and either power block.
- Validated 24.405 mm between the lowest control opening and the conservative power-block envelopes.

## [R0.10] — 2026-07-23

### USB-PD card placement

- Preserved the complete R0.9 body geometry for compatibility with the body already being printed.
- Added four blind M3 heat-set-insert bosses to the underside of the lid.
- Added a removable 114 × 30 mm carrier for two 45.72 × 17.78 mm USB-PD card envelopes.
- Added open-ended locating rails and two zip-tie retention points per card.
- Assigned the left bay to the battery PD sink/trigger and the right bay to the Starlink PD source.
- Added a dimensioned placement and wiring map.
- Validated zero interference with the body and both power blocks, including conservative 8 mm-deep card envelopes.

## [R0.9] — 2026-07-23

### Final draft

- Incorporated the confirmed 18.55 mm USB-C screw centers into both body interfaces.
- Incorporated the confirmed 120.65 mm (4.75 inch) unfused-busbar centers into the body and final coupon.
- Replaced exploratory USB coupons with a single engraved 18.55 mm final coupon.
- Regenerated synchronized STEP, STL, and 3MF files plus the complete ZIP release.
- Revalidated the 146 × 96 × 52 mm enclosure, zero body/lid interference, and zero conservative power-block envelope interference.

## [R0.8] — 2026-07-22

### Changed

- Refactored both USB-C openings around the received 12.70 × 6.35 mm pass-through body and 25.40 × 7.62 mm rounded flange.
- Enlarged the enclosure from 140 × 90 × 52 mm to 146 × 96 × 52 mm so the covered unfused busbar and Blue Sea 5045 can mount side-by-side.
- Replaced provisional unfused-busbar slots with fixed mounting holes at the physically measured 114.30 mm centers.
- Relocated the lid posts and internal tie-downs to clear both power-block envelopes.
- Removed obsolete PCB-backed USB shelves; the received interfaces are cable-backed fittings.

### Added

- Three-position USB-C fit coupon using 18.80, 19.05, and 19.30 mm screw-center variants.
- Automated conservative-envelope clearance checks for both power blocks and the enclosure.

## [R0.7] — 2026-07-22

### Changed

- Corrected the outside-reading orientation of the `BATTERY`, `STARLINK`, and `PEPLINK` body labels.
- Added `VOLTAGE` and `POWER` labels to the outside control face.
- Preserved the verified control openings, 4.10 × 2.40 mm Peplink exit, and 4.55 × 2.70 mm strain-relief channel.

### Added

- Blue Sea 5045 fused-block riser coupon using the documented 65.1 mm mounting centers.
- Provisional full-envelope coupon for the supplied 137.16 × 38.10 × 22.86 mm unfused busbar.

### Hold point

- The unfused busbar cover is 3.16 mm longer than the enclosure's 134 mm internal length. Its body mounting remains deferred until the physical component and final orientation are verified.

## [R0.6] — 2026-07-22

### Changed

- Preserved the physically verified R0.5 switch and voltmeter openings.
- Selected the smallest successful Peplink wire-coupon opening: 4.10 × 2.40 mm.
- Enlarged the strain-relief cable channel by 0.50 mm overall in width and height, to 4.55 × 2.70 mm.
- Preserved the 18 × 10 mm clamp footprint and screw spacing.

## [R0.5] — 2026-07-22

### Changed

- Widened the R0.4 voltmeter opening by 1.00 mm overall, adding 0.50 mm on the left and right.
- Retained the verified 26.39 mm voltmeter-opening height.
- Final voltmeter cutout: 45.17 × 26.39 mm.

### Added

- Synchronized STEP, STL, and 3MF files.
- Parametric CadQuery generator.
- Fit coupons, dimensions manifest, validation report, checksums, preview, and complete ZIP release.

## [R0.4] — 2026-07-22

- Reduced the R0.3 voltmeter opening by 2.00 mm in width and height after the first physical coupon rattled.
- Voltmeter cutout was 44.17 × 26.39 mm.

## [R0.3] — 2026-07-21

- Replaced generic USB-C openings with AAOTOKK panel-mount geometry.
- Added Blue Sea 5045 mounting bosses and reserved footprint.
- Added cable-routing rails and tie-down tabs.
- Resized the Peplink exit and clamp for the measured 3.81 × 2.03 mm bonded 20 AWG cable.
- Added `BATTERY`, `STARLINK`, and `PEPLINK` labels.
- Corrected inherited lid-lip interference and preserved the removable branded lid.
- Generated and cross-validated STEP, STL, and 3MF exports.

## [Milestone 1 baseline]

- Established the initial repository, conceptual requirements, documentation, and contribution workflow.

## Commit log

2026-07-22 Add Mission Communications Hub Mk I R0.5 release
    [MCH-MkI_AAOTOKK_USB-C_fit_coupon_R0.5.3mf, MCH-MkI_AAOTOKK_USB-C_fit_coupon_R0.5.step, MCH-MkI_AAOTOKK_USB-C_fit_coupon_R0.5.stl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]
2026-07-22 Add Mission Communications Hub Mk I R0.6 release
    [MCH-MkI_AAOTOKK_USB-C_fit_coupon_R0.6.3mf, MCH-MkI_AAOTOKK_USB-C_fit_coupon_R0.6.step, MCH-MkI_AAOTOKK_USB-C_fit_coupon_R0.6.stl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]
2026-07-22 Add Mission Communications Hub Mk I R0.7 release
    [MCH-MkI_AAOTOKK_USB-C_fit_coupon_R0.7.3mf, MCH-MkI_AAOTOKK_USB-C_fit_coupon_R0.7.step, MCH-MkI_AAOTOKK_USB-C_fit_coupon_R0.7.stl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]
2026-07-23 Refactor USB and busbar mounting for R0.8
    [MCH-MkI_BlueSea5045_fused_block_riser_coupon_R0.8.3mf, MCH-MkI_BlueSea5045_fused_block_riser_coupon_R0.8.step, MCH-MkI_BlueSea5045_fused_block_riser_coupon_R0.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]
2026-07-23 Add R0.8A USB fit refinement coupon
    [MCH-MkI_USB-C_panel_fit_coupon_18.70-18.75_R0.8A.3mf, MCH-MkI_USB-C_panel_fit_coupon_18.70-18.75_R0.8A.step, MCH-MkI_USB-C_panel_fit_coupon_18.70-18.75_R0.8A.s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]
2026-07-23 Add R0.8B USB and busbar refinement coupons
    [MCH-MkI_USB-C_panel_fit_coupon_18.60-18.65_R0.8B.3mf, MCH-MkI_USB-C_panel_fit_coupon_18.60-18.65_R0.8B.step, MCH-MkI_USB-C_panel_fit_coupon_18.60-18.65_R0.8B.s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]
2026-07-23 Add R0.8C 18.55 mm USB fit coupon
    [MCH-MkI_USB-C_panel_fit_coupon_18.55mm_R0.8C.3mf, MCH-MkI_USB-C_panel_fit_coupon_18.55mm_R0.8C.step, MCH-MkI_USB-C_panel_fit_coupon_18.55mm_R0.8C.stl]
2026-07-23 Create Mission Communications Hub R0.9 final draft
    [MCH-MkI_BlueSea5045_fused_block_riser_coupon_R0.9.3mf, MCH-MkI_BlueSea5045_fused_block_riser_coupon_R0.9.step, MCH-MkI_BlueSea5045_fused_block_riser_coupon_R0.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]
2026-07-23 Add R0.10 USB-PD card carrier
    [MCH-MkI_BlueSea5045_fused_block_riser_coupon_R0.10.3mf, MCH-MkI_BlueSea5045_fused_block_riser_coupon_R0.10.step, MCH-MkI_BlueSea5045_fused_block_riser_coupon_R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]
2026-07-23 Add R0.11 tall swapped-block body
    [MCH-MkI_BlueSea5045_fused_block_riser_coupon_R0.11.3mf, MCH-MkI_BlueSea5045_fused_block_riser_coupon_R0.11.step, MCH-MkI_BlueSea5045_fused_block_riser_coupon_R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]
2026-07-24 Add R0.12 side-by-side PD carrier and lid
    [MCH-MkI_BlueSea5045_fused_block_riser_coupon_R0.12.3mf, MCH-MkI_BlueSea5045_fused_block_riser_coupon_R0.12.step, MCH-MkI_BlueSea5045_fused_block_riser_coupon_R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]
